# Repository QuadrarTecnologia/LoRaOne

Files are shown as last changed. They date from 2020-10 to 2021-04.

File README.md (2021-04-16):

# Quadrar Tecnologia ##

We are a Design House focused on IoT projects, working with large companies to solve complex challenges, developing innovative products.

## README #

## What is this repository for? ##
Quadrar's Public Repository for documents, application notes, example codes and usage for the LoRaONE Module.

## How this repository is arranged? ##

This repository is arranged by sub folders:

* LoRaONE Application Notes - Module's application notes documents;

* LoRaONE Code Examples - Application and code examples for module's usage;

* LoRaONE DevBoard - Board's Gerber Files and BOM for manufacture;

* LoRaONE Documents - Module's Datasheet, Manuals and References;

## Extern References ##

* LoRaONE: primeiro módulo LoRa nacional de baixo custo: https://www.embarcados.com.br/loraone-primeiro-modulo-lora-nacional-de-baixo-custo/

* Conheça a Quadrar LoRaONE DevBoard : https://www.embarcados.com.br/quadrar-loraone-devboard/

* Webinar gravado para o Embarcados: Aplicando a LoRaONE DevBoard nos seus projetos de IoT: https://www.embarcados.com.br/webinars/webinar-aplicando-a-loraone-devboard-nos-seus-projetos-de-iot/

## Who do I talk to? ##

* Quadrar Tecnologia 	- contato@quadrar.com.br

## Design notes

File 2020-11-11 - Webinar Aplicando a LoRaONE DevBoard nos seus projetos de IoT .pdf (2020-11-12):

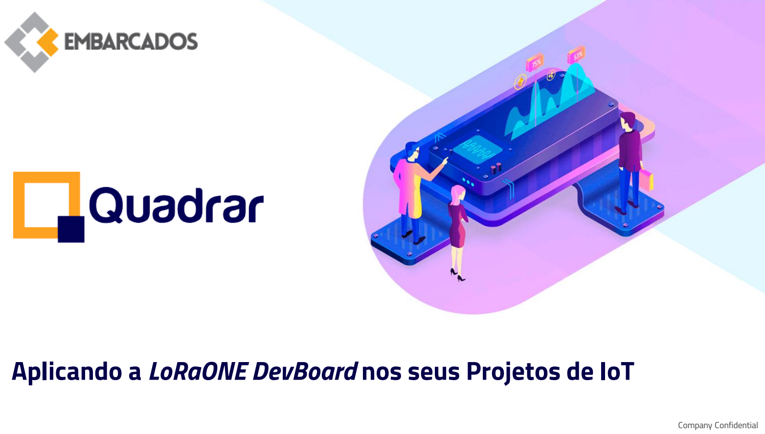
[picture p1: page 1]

# Aplicando a LoRaONE DevBoard nos seus Projetos de IoT

Company Confidential

A Quadrar Tecnologia (http://www.quadrar.com.br/) é uma Design House focada em projetos de IoT,

# trabalhando a mais de 10 anos com grandes empresas, para resolver

desafios complexos e desenvolvendo produtos inovadores.

# Nossos Clientes

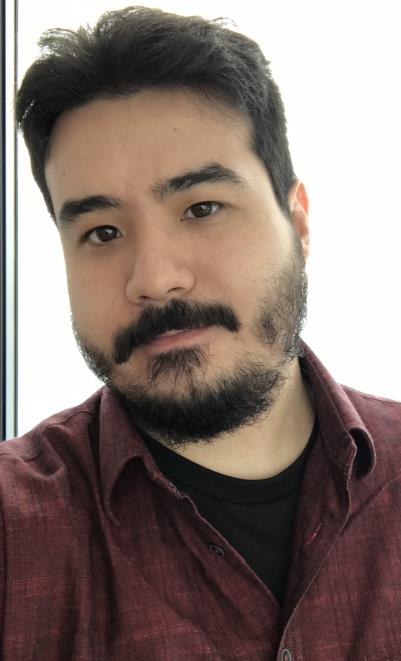
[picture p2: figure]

# Airton Toyofuku

## CTO e Engenheiro na Quadrar Tecnologia

### Engenheiro eletricista com vivência de mais de 10 anos na área de desenvolvimento de

sistemas embarcados, arquiteturas em nuvem e gestão de projetos.

### Possui formação em Engenharia Elétrica, com Ênfase em Eletrônica, Especialista em Controle e Automação, ambas pela FEI. Especialista em Projetos de Sistemas Digitais e

Eletrônica Embarcada pela SAE, e MBA em Gestão de Projetos pela FGV.
Por influência de grandes nomes do empreendedorismo, estuda técnicas de gestão, liderança, estratégia, economia, investimentos e inovação.
Nas horas vagas, é arqueiro, baixista, pescador e entusiasta do mercado financeiro.

# Apresentação

# 1. Apresentação 2. O que é LoRaWAN? 3. Características do Módulo LoRaONE 4. Características da DevBoard 5. Integração com Projetos IoT 6. Repositório de Conhecimento 7. Valores e Forma Aquisição 8. Referências 9. Agradecimentos

# Agenda

# O que é LoRaWAN?

# O que é LoRaWAN?

# O que é LoRaWAN?

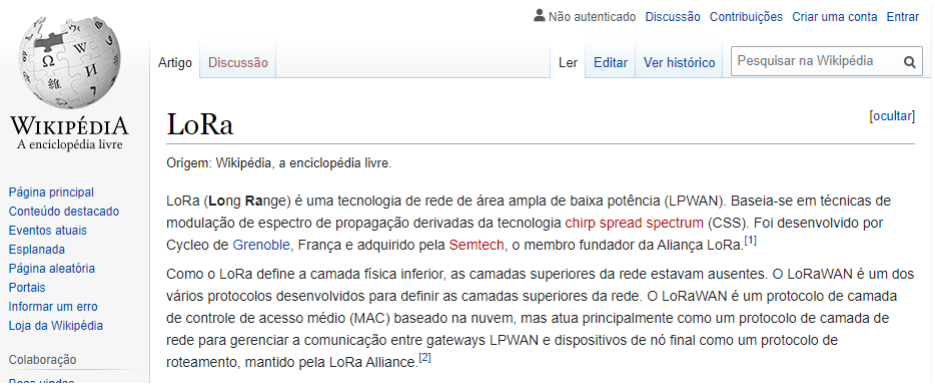
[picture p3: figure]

Fonte: https://pt.wikipedia.org/wiki/LoRa

# O que é LoRaWAN?

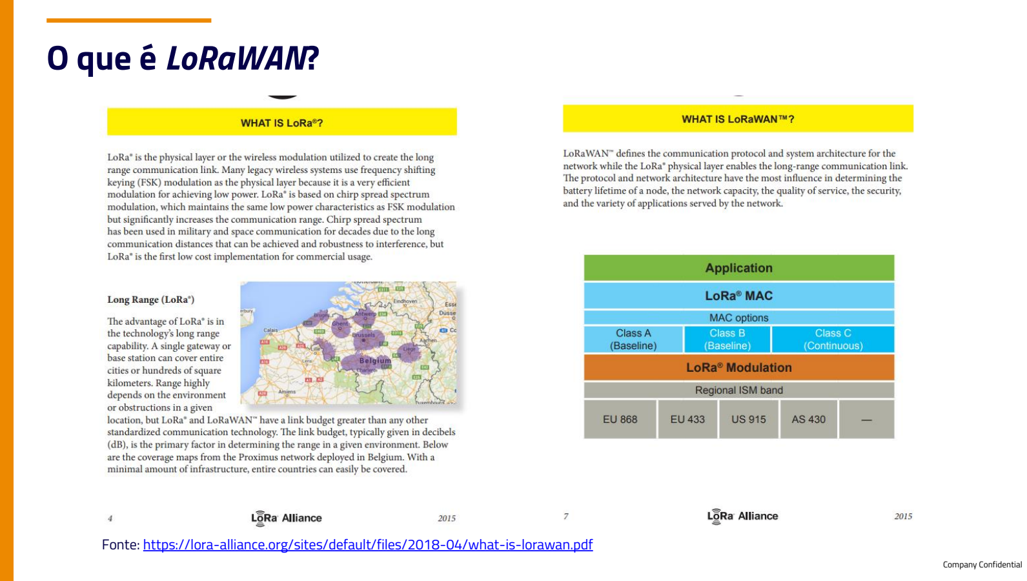
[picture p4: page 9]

Fonte: https://lora-alliance.org/sites/default/files/2018-04/what-is-lorawan.pdf

# O que é LoRaWAN?

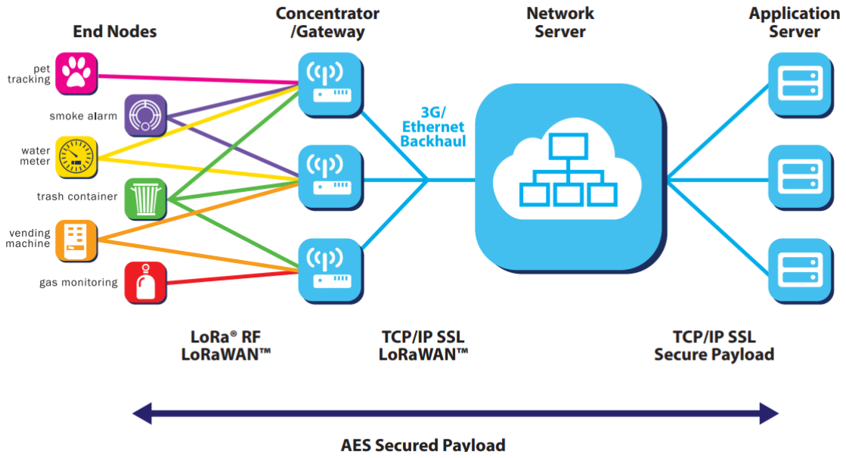
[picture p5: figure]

Fonte: https://lora-alliance.org/sites/default/files/2018-04/what-is-lorawan.pdf

# O que é LoRaWAN?

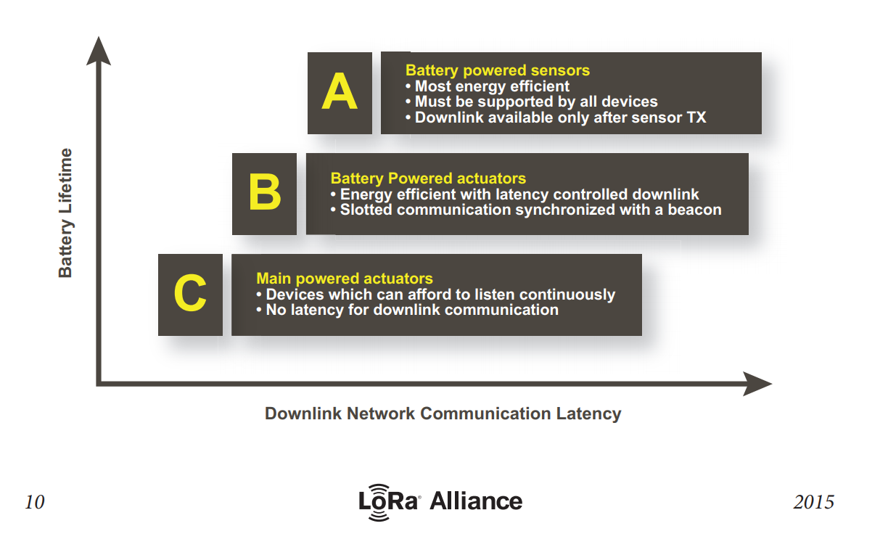
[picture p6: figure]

Fonte: https://lora-alliance.org/sites/default/files/2018-04/what-is-lorawan.pdf

# Características do Módulo LoRaONE

# Características do Módulo LoRaONE

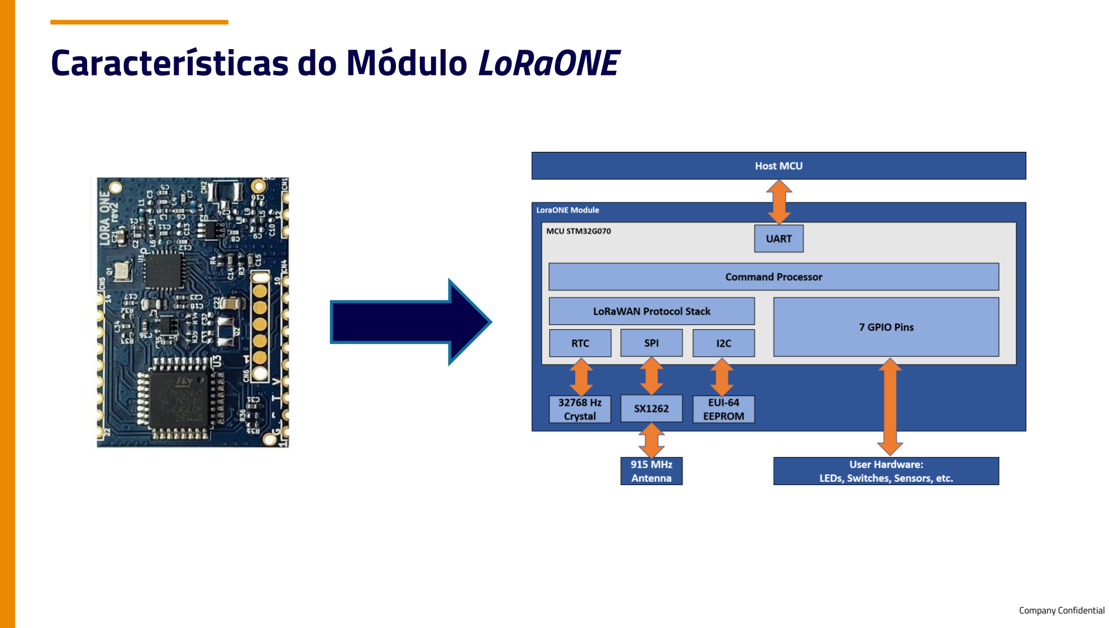
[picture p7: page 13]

# Características do Módulo LoRaONE

Specification | Min. | Typ. | Max | Units
Core MCU | STM32G070CB/KB
Core Radio | Semtech SX1262
Supply Voltage | 3.1 | 3.3 | 3.6 | V
Consumption in reception (LNA on) | | 5.3 | | mA
Consumption in reception (LNA off) | | 4.6 | | mA
Consumption in transmission at 22dBm | | 118 | | mA
Consumption in transmission at 20dBm | | 90 | | mA
Consumption in transmission at 17dBm | | 75 | | mA
Consumption in transmission at 14dBm | | 63 | | mA
Consumption in deep sleep mode | | 5 | | uA
Power-down reset threshold | 1.96 | 2.00 | 2.04 | V
GPIO pin current (each) | | 15 | | mA
GPIO pin current (total) | | 80 | | mA
Interface | UART
Baud rate | | 9600 | | bps
LoRaWAN band AU915/LA915 | 915 to 928 MHz
LoRaWAN network link budget - Reception | | 163 | | dBm
LoRaWAN network link budget - Transmission | | 159 | | dBm
Reception sensitivity | | -137 | | dBm
RF connection | three 50 Ohms options, see page 6
Operating temperature | -40 | | 85 | ºC
Operating humidity | 10 | | 90 | %

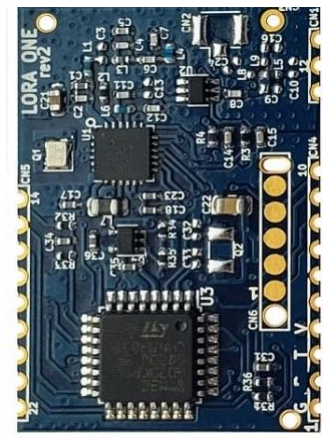
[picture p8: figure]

# Características do Módulo LoRaONE

Pin | Name | Description
1 | GND | Connected to Ground
2 | mRx | Connected to Host RX
3 | mTx | Connected to Host TX
4 | VCC | Connected to 3v3
5 | CTS | Serial flow control/GPIO
6 | RTS | Serial flow control/GPIO
7 | --- | Reserved
8 | RST | Reset
9 | --- | Reserved
10 | --- | Reserved
11 | GND | Connected to Ground
12 | Antenna | Antenna signal output
13 | GND | Connected to Ground
14 | VBAT | Battery Measurement
15 | GPIO7 | Generic GPIO
16 | GPIO6 | Generic GPIO
17 | GPIO5 | Generic GPIO
18 | GPIO4 | Generic GPIO
19 | GPIO3 | Generic GPIO
20 | GPIO2 | Generic GPIO
21 | GPIO1 | Generic GPIO
22 | GND | Connected to Ground

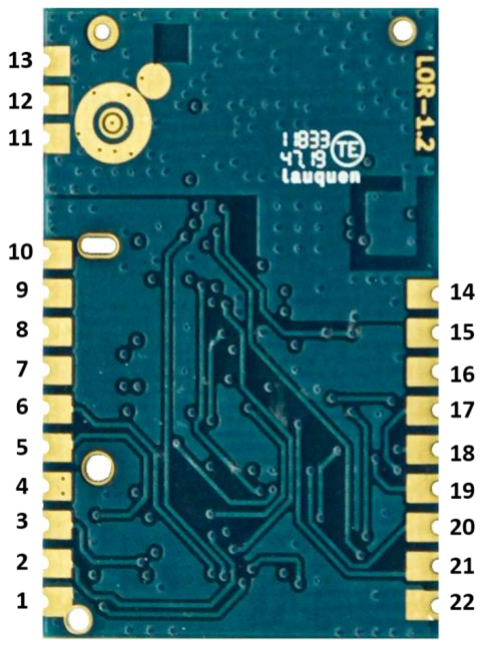
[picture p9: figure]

# Características do Módulo LoRaONE

# Características do Módulo LoRaONE

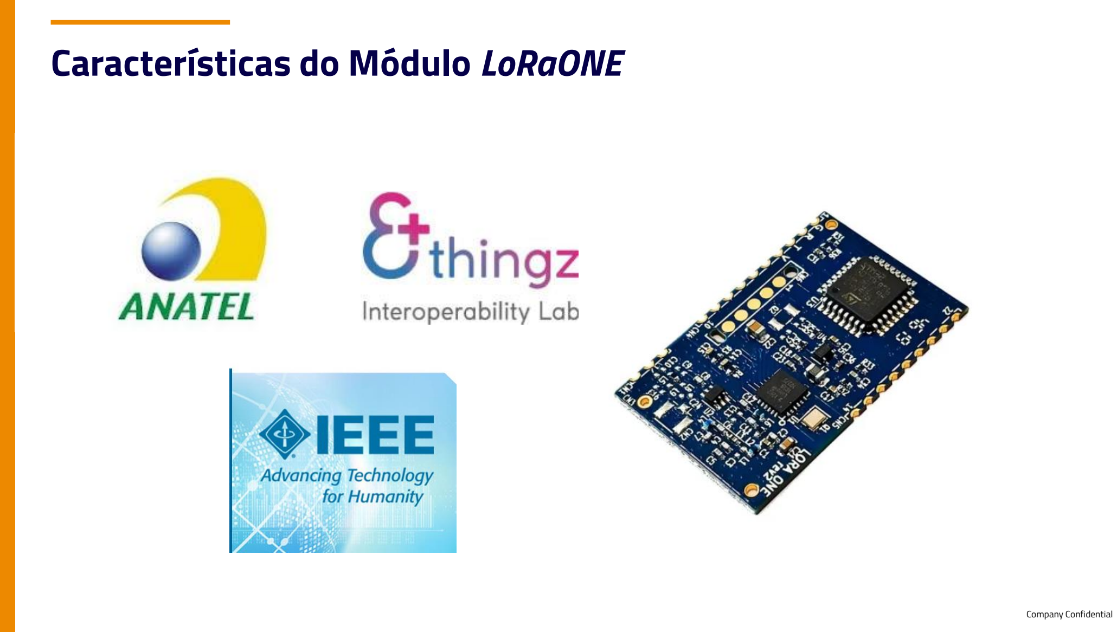
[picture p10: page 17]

# Características da DevBoard

# Características da DevBoard

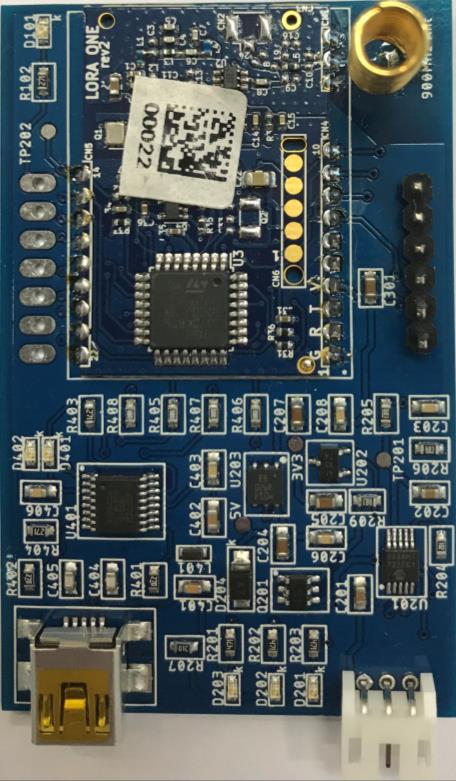
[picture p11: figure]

Além das características do Módulo LoRaONE...

✓ Alimentação via Mini USB com entrada de 5,0 Volts;
✓ Conversor USB-Serial FTDI, para acesso ao console de comandos AT;
✓ Circuito carregador de bateria, baseado no MCP73833, com LEDs de indicação de carga; ✓ Chave Eletrônica para comutação automática entre bateria e fonte principal;
✓ LDO de 3,3 Volts / 2,0 Amperes;
✓ Acesso aos GPIOs via Header Pin;
✓ Acesso a USART de comandos AT via Header Pin;
✓ Acesso a 3,3 Volts, 5,0 Volts e GND via Header Pin; ✓ Antena Helicoidal de 4dBI, customizável;
✓ Dimensões de 63,5 x 40 mm;

# Características da DevBoard

Pronta para sua aplicação que requer...

✓ Leitura de sensores diversos;
✓ Entradas e saídas digitais;
✓ Autonomia via bateria de lítio;
✓ Alimentação via fonte “simples” de 5,0 Volts;
✓ Possibilidade da customização do software do MCU;

# Integração com Projetos IoT

# Integração com Projetos IoT

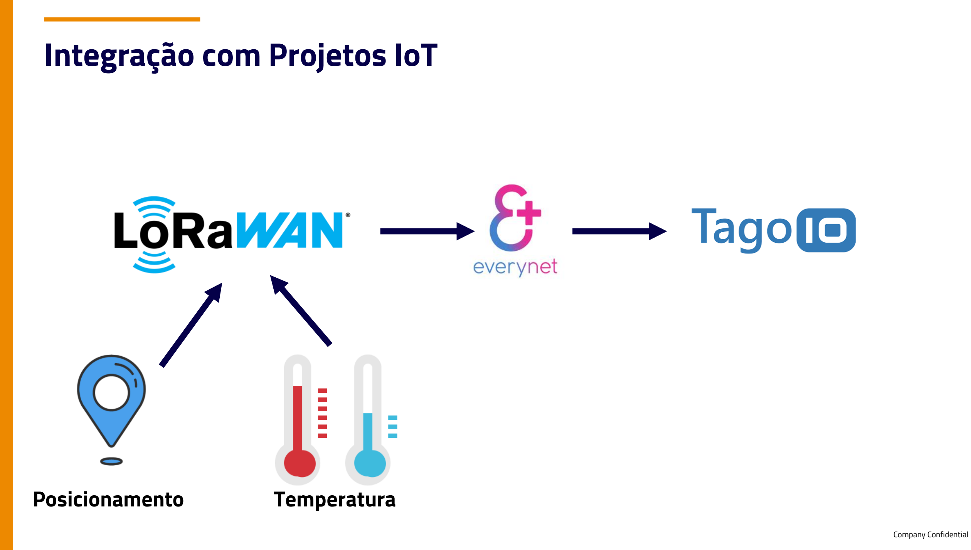
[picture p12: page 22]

# Posicionamento Temperatura

# Integração com Projetos IoT

# Integração com Projetos IoT

GPS TX | 5,0 Volts | LoRa TX
GPS RX | GND | LoRa RX
5,0 Volts | Data OneWire (Resistor de 10k – 3V3) | 5,0 Volts
GND | | GND

# Integração com Projetos IoT

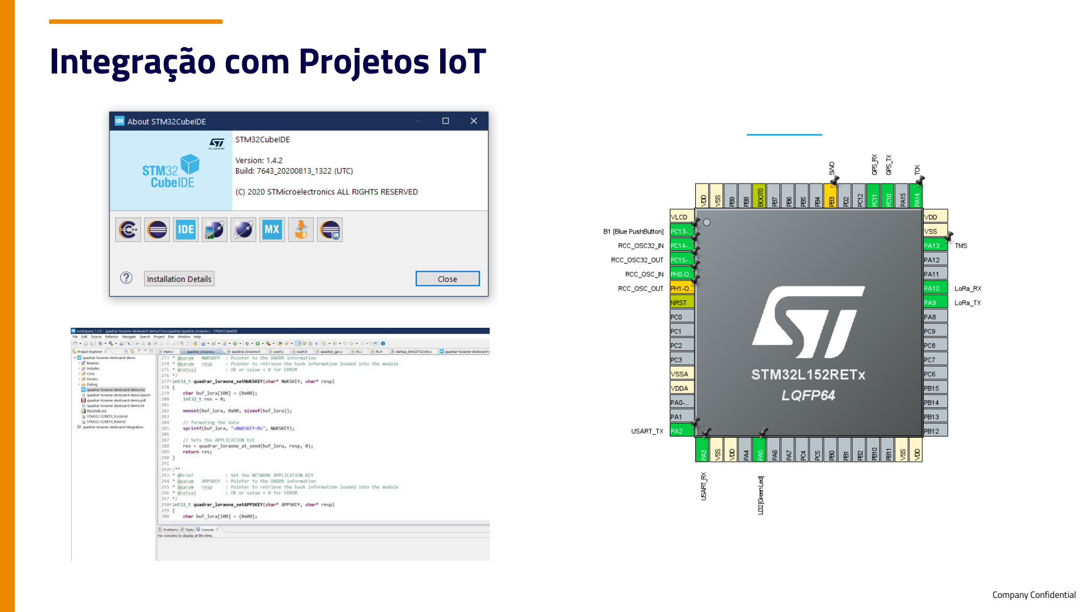
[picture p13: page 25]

# Integração com Projetos IoT

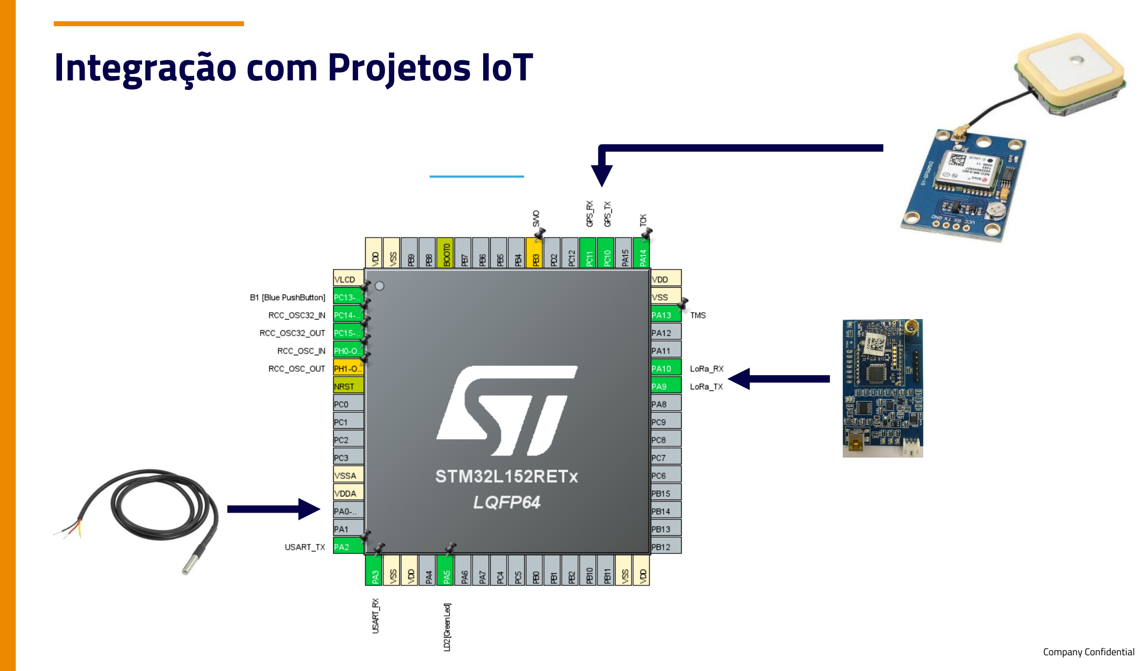
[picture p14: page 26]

# Integração com Projetos IoT

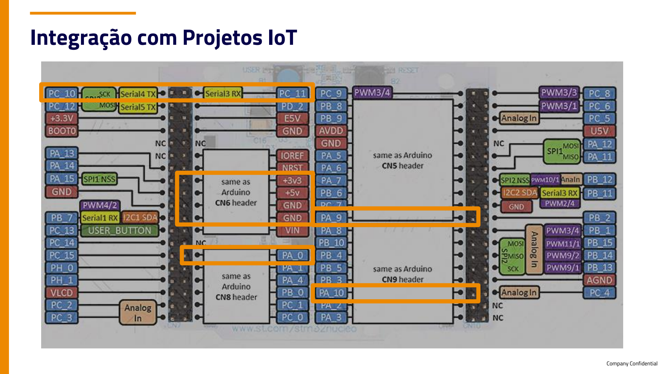
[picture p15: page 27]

# Integração com Projetos IoT

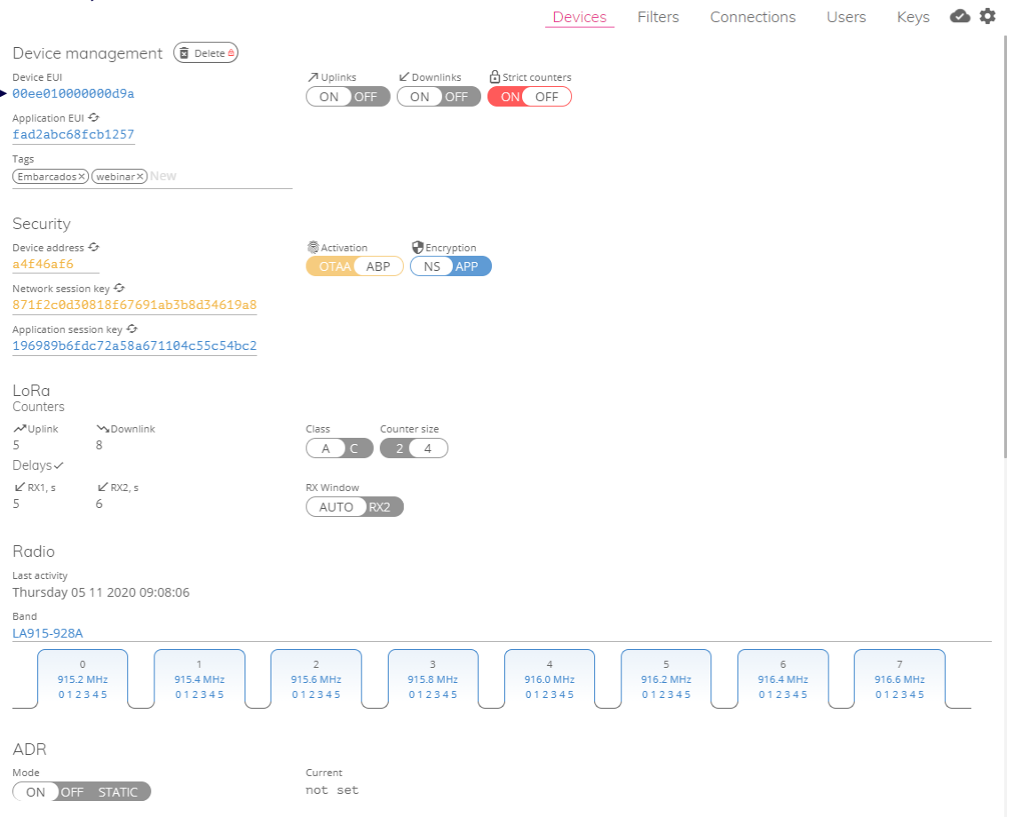
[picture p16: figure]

# Vem no Módulo

# Integração com Projetos IoT

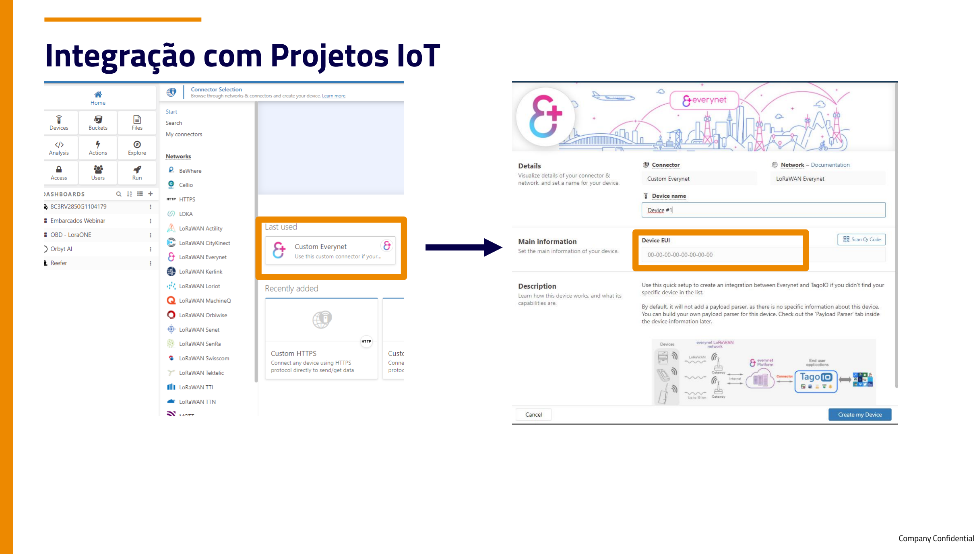
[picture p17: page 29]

# Integração com Projetos IoT

# Integração com Projetos IoT

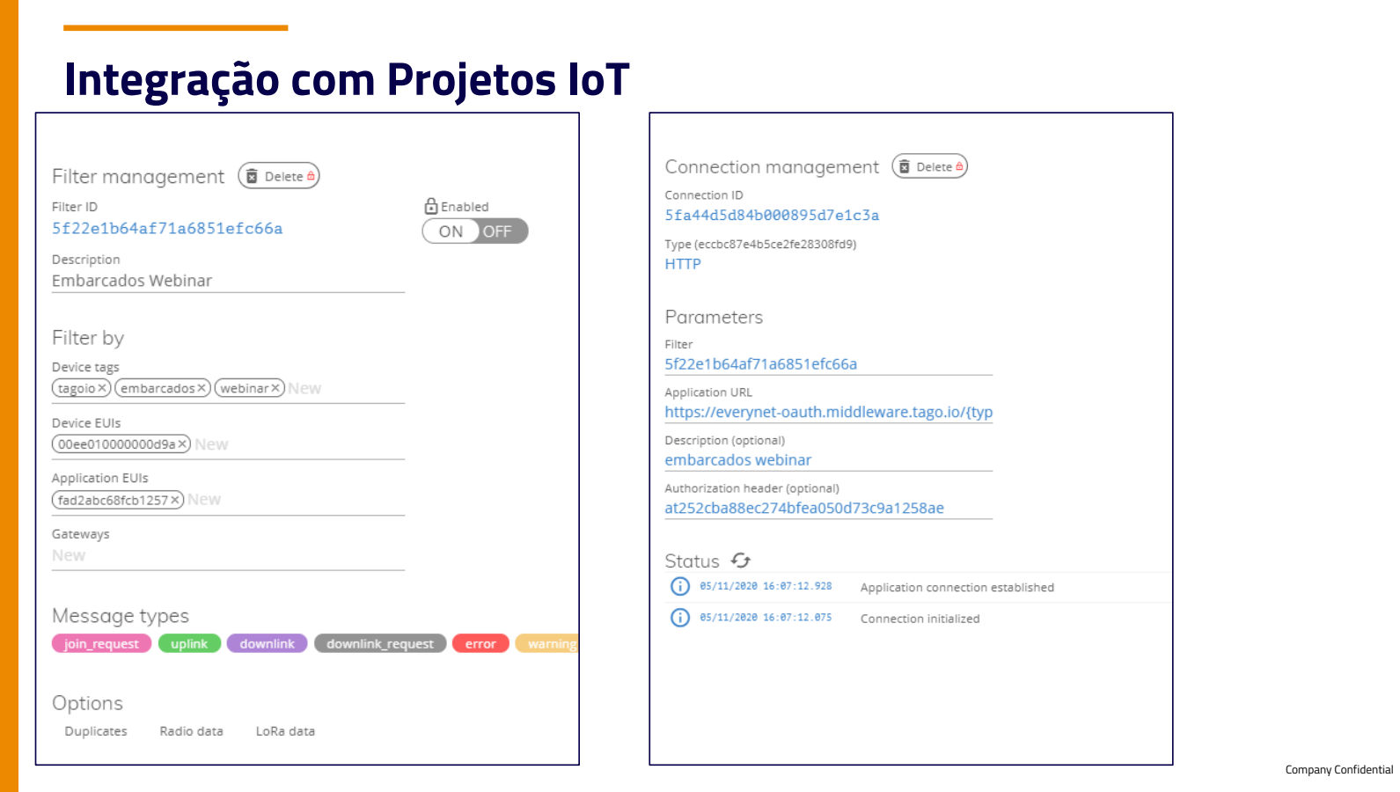
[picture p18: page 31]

# Integração com Projetos IoT

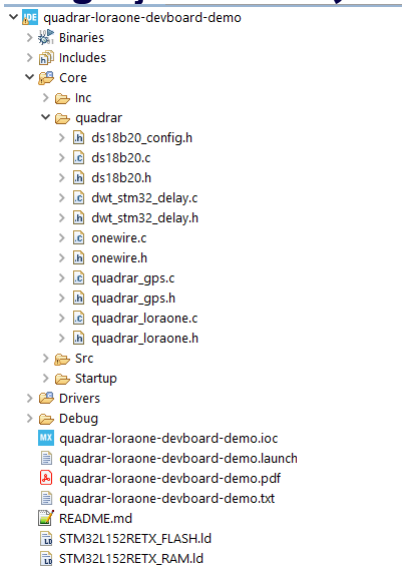
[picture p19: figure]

# Integração com Projetos IoT

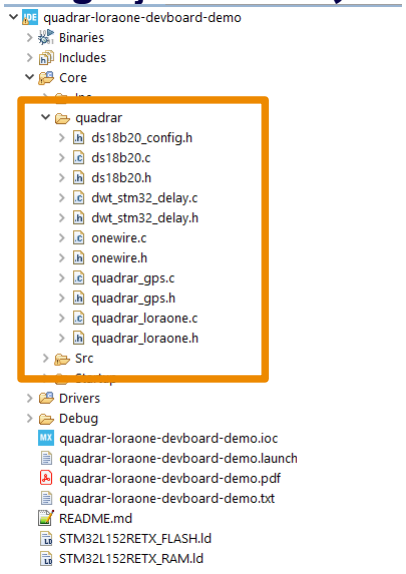
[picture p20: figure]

# Integração com Projetos IoT

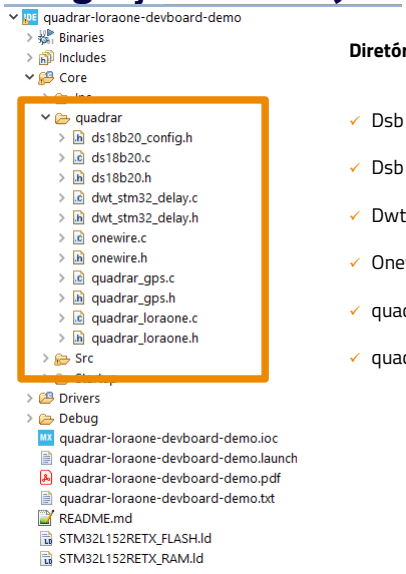
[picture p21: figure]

## Diretório quadrar:

✓ Dsb1820_config -> Configuração do GPIO para leitura do OneWire;
✓ Dsb1820.c/h -> Biblioteca do sensor de temperatura;
✓ Dwt_stm32_delay.c/h -> Controles de tempo para leitura do protocolo OneWire; ✓ Onewire.c/h -> Driver utilizado pelo sensor;
✓ quadrar_gps.c/h -> Biblioteca do GPS;
✓ quadrar_loraone.c/h -> Biblioteca de controle do módulo LoRaOne;

# Integração com Projetos IoT

// Everynet Information -> Must be exclusive for each device typedef struct
{
char* | DEUI;
char* | APPEUI;
char* | DADDR;
char* | NWKSKEY;
char* | APPSKEY;
} quadrar_loraone_data_t;

/* Publics function prototypes -----------------------------------------------*/
int32_t quadrar_loraone_init(void);
int32_t quadrar_loraone_reset(void);
int32_t quadrar_loraone_sleep(void);
int32_t quadrar_loraone_join(quadrar_loraone_join_t mode); int32_t quadrar_loraone_getDEUI (char* DEUI);
int32_t quadrar_loraone_setAPPEUI(char* APPEUI, char* resp); int32_t quadrar_loraone_setDADDR(char* DADDR, char* resp); int32_t quadrar_loraone_setNWKSKEY(char* NWKSKEY, char* resp); int32_t quadrar_loraone_setAPPSKEY(char* APPSKEY, char* resp); int32_t quadrar_loraone_send_data(int port, char* data);

# Integração com Projetos IoT

// Everynet Information -> Must be exclusive for each device
#define LoRaONE_APPEUI | (char*)"fad2abc68fcb1257"

#define LoRaONE_NWKSKEY | (char*)"871f2c0d30818f67691ab3b8d34619a8"

#define LoRaONE_APPSKEY | (char*)"196989b6fdc72a58a671104c55c54bc2"

#define LoRaONE_DADDR | (char*)"a4f46af6"

int main(void)
{
int32_t res = 0;
for(;;)
{
res = quadrar_loraone_init(); if(!res)
break;
}

for(;;)
{
quadrar_loraone_send_data(1,"BlaBlaBla!"); HAL_Delay(5000);
}

# Integração com Projetos IoT

Vamos a prática...

# Repositório de Conhecimento

# Repositório de Conhecimento

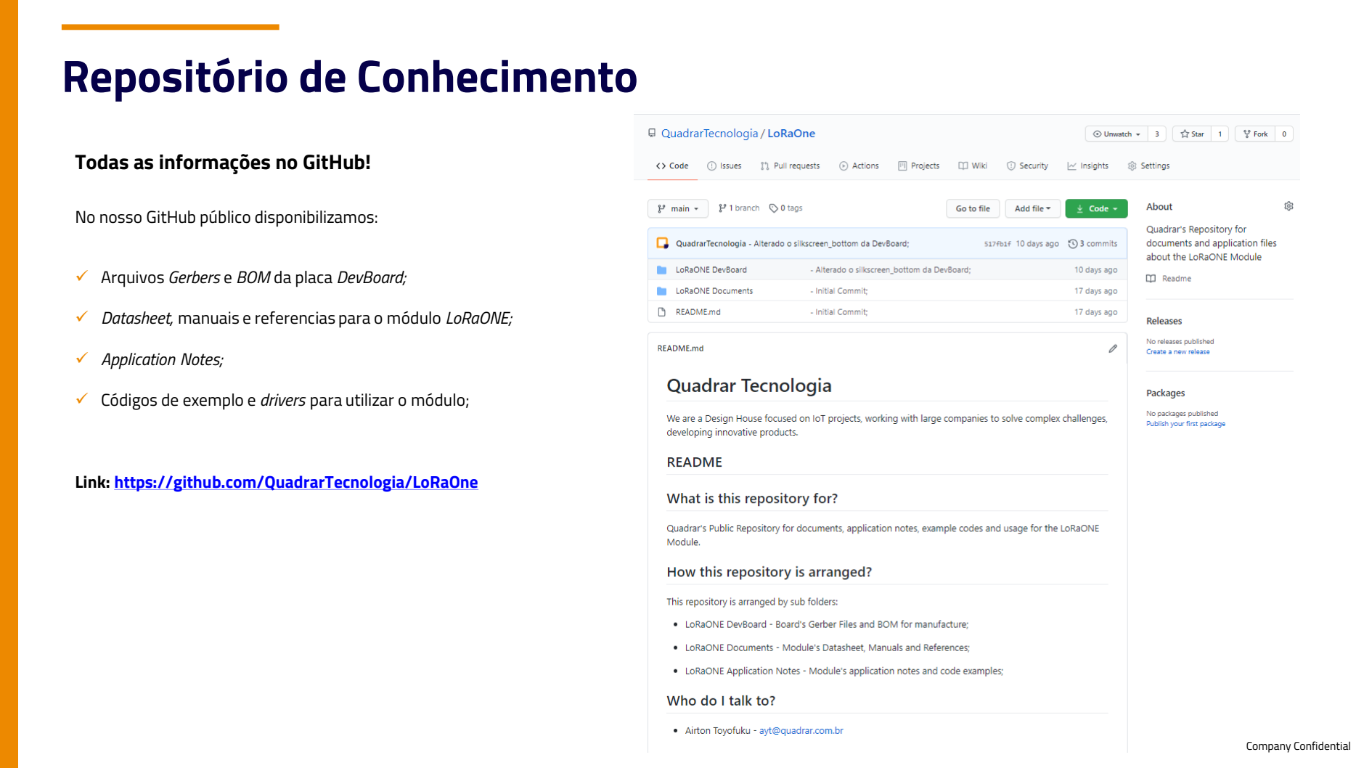
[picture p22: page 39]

### Todas as informações no GitHub!

No nosso GitHub público disponibilizamos:

✓ Arquivos Gerbers e BOM da placa DevBoard;
✓ Datasheet, manuais e referencias para o módulo LoRaONE; ✓ Application Notes;
✓ Códigos de exemplo e drivers para utilizar o módulo;

Link: https://github.com/QuadrarTecnologia/LoRaOne

# Valores e Formas de Aquisição

# Valores e Formas de Aquisição

### Os valores praticados para o Módulo LoRaONE são públicos:

Para volumes praticados na Industria, a tabela de valores é pública, já contabilizada com os impostos de PIS/COFINS, ICMS e IPI:

Para amostras, ou aquisição em baixos volumes, disponibilizamos um link no Mercado Livre para compra direta:
https://produto.mercadolivre.com.br/MLB-1432558473-modulo-lorawan-_JM?quantity=1.
Quantidade | Preço com Impostos (US$)
Até 10.000 | 16,90
10.001 a 50.000 | 16,12
50.001 a 100.000 | 15,35
mais de 100.000 | 14,57

# Valores e Formas de Aquisição

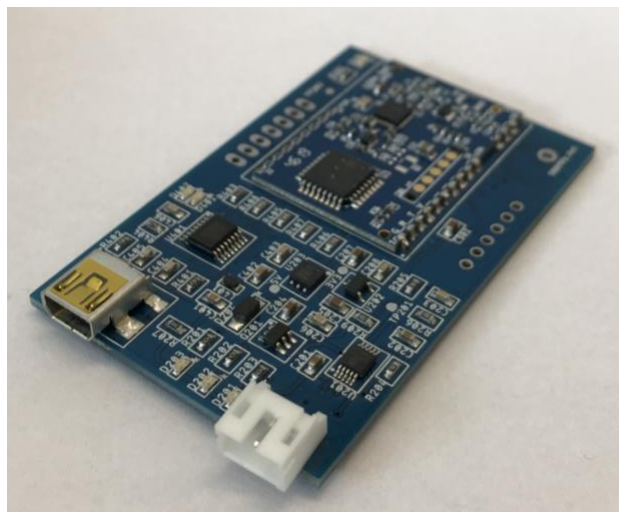
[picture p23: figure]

A expectativa de valor para a placa é de R$ 215,00, com previsão de disponibilidade em meados de dezembro de 2020.

O valor se deve ao baixo volume praticado para lotes iniciais de aquisição e ele pode ser negociado, dependendo da sua aplicação e volume, da mesma forma que é pratico pelo Módulo LoRaONE.

Também pode ser utilizada em projetos especiais, com customização de software, adequando-se a aplicação necessária.

Para amostras, ou aquisição em baixos volumes, disponibilizaremos um link no Mercado Livre para compra direta em Dezembro de 2020.

# Referências

# Referêcias

## LoRa segundo a Wekipedia: https://pt.wikipedia.org/wiki/LoRa

LoRaWAN pela LoRa Alliance: https://lora-alliance.org/sites/default/files/2018-04/what-is-lorawan.pdf

## Quadrar Tecnologia: https://quadrar.com.br

## Quadrar Tecnologia no Linkedin: https://www.linkedin.com/company/quadrartecnologia/

## Quadrar Tecnologia no Youtube: https://www.youtube.com/channel/UC3zlF7_kq0bqnCLDcLuwKrg

## Repositório da Quadrar Tecnologia no GitHub: https://github.com/QuadrarTecnologia/LoRaOne

LoRaONE no Mercado Livre: https://produto.mercadolivre.com.br/MLB-1432558473-modulo-lorawan-_JM?quantity=1.

## Application Server da Tago.io: https://tago.io/

## Network Server da Everynet: https://ns.atc.everynet.io/login

# Agradecimentos

Obrigado.

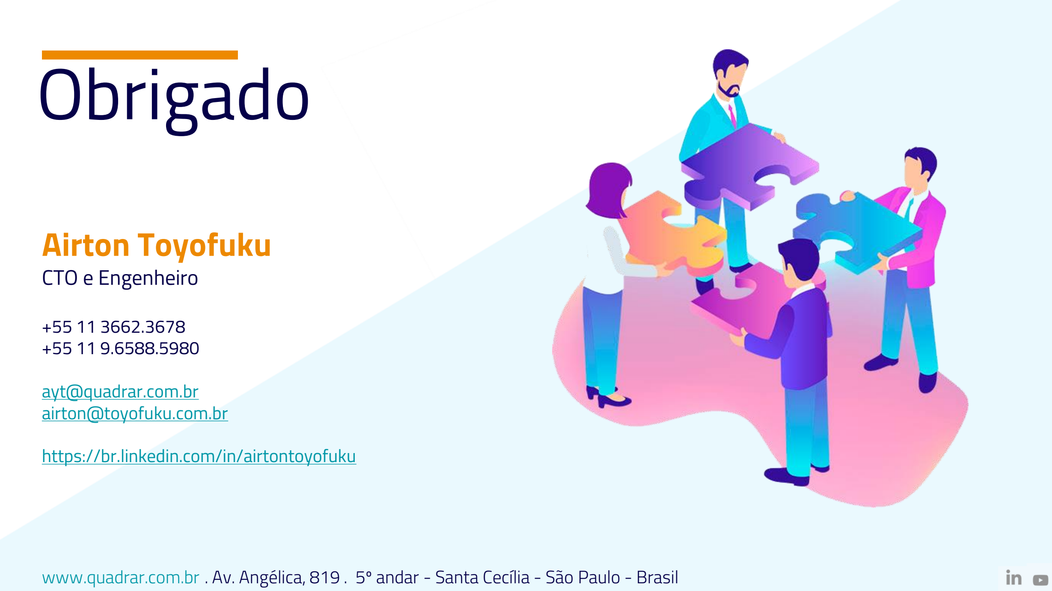
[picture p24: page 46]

## www.quadrar.com.br . Av. Angélica, 819 . 5º andar - Santa Cecília - São Paulo - Brasil

# Airton Toyofuku

## CTO e Engenheiro

+55 11 3662.3678
+55 11 9.6588.5980

## ayt@quadrar.com.br airton@toyofuku.com.br https://br.linkedin.com/in/airtontoyofuku

# Quadrar Tecnologia - Mais do que uma empresa de IoT Somos parceiros do seu negócio

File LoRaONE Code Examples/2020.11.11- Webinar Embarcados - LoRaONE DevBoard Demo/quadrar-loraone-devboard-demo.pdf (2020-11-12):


30/10/2020

quadrar-loraone-devboard-demo Project Configuration Report

## 1. Description

### 1.1. Project

Project Name | quadrar-loraone-devboard-demo
Board Name | NUCLEO-L152RE
Generated with: | STM32CubeMX 6.0.1
Date | 10/30/2020

### 1.2. MCU

MCU Series | STM32L1
MCU Line | STM32L151/152
MCU name | STM32L152RETx
MCU Package | LQFP64
MCU Pin number | 64

### 1.3. Core(s) information

Core(s) | Arm Cortex-M3

## 2. Pinout Configuration


## 3. Pins Configuration

Pin Number LQFP64 | Pin Name (function after reset) | Pin Type | Alternate Function(s) | Label
1 | VLCD | Power
2 | PC13-WKUP2 | I/O | GPIO_EXTI13 | B1 [Blue PushButton]
3 | PC14-OSC32_IN | I/O | RCC_OSC32_IN
4 | PC15-OSC32_OUT | I/O | RCC_OSC32_OUT
5 | PH0-OSC_IN | I/O | RCC_OSC_IN
6 | PH1-OSC_OUT * | I/O | RCC_OSC_OUT
7 | NRST | Reset
12 | VSSA | Power
13 | VDDA | Power
16 | PA2 | I/O | USART2_TX | USART_TX
17 | PA3 | I/O | USART2_RX | USART_RX
18 | VSS | Power
19 | VDD | Power
21 | PA5 ** | I/O | GPIO_Output | LD2 [Green Led]
31 | VSS | Power
32 | VDD | Power
42 | PA9 | I/O | USART1_TX | LoRa_TX
43 | PA10 | I/O | USART1_RX | LoRa_RX
46 | PA13 | I/O | SYS_JTMS-SWDIO | TMS
47 | VSS | Power
48 | VDD | Power
49 | PA14 | I/O | SYS_JTCK-SWCLK | TCK
51 | PC10 | I/O | UART4_TX | GPS_TX
52 | PC11 | I/O | UART4_RX | GPS_RX
55 | PB3 * | I/O | SYS_JTDO-TRACESWO | SWO
60 | BOOT0 | Boot
63 | VSS | Power
64 | VDD | Power

** The pin is affected with an I/O function
* The pin is affected with a peripheral function but no peripheral mode is activated

## 4. Clock Tree Configuration


## 5. Software Project

### 5.1. Project Settings

Name | Value
Project Name | quadrar-loraone-devboard-demo
Project Folder | D:\Workspace\STM32CubeIDE\workspace_1.2.0\quadrar-loraone-devboard-
Toolchain / IDE | STM32CubeIDE
Firmware Package Name and Version | STM32Cube FW_L1 V1.10.1
Application Structure | Advanced
Generate Under Root | Yes
Do not generate the main() | No
Minimum Heap Size | 0x200
Minimum Stack Size | 0x400

### 5.2. Code Generation Settings

Name | Value
STM32Cube MCU packages and embedded software | Copy only the necessary library files
Generate peripheral initialization as a pair of '.c/.h' files | Yes
Backup previously generated files when re-generating | No
Keep User Code when re-generating | Yes
Delete previously generated files when not re-generated | Yes
Set all free pins as analog (to optimize the power consumption) | Yes
Enable Full Assert | No

### 5.3. Advanced Settings - Generated Function Calls

Rank | Function Name | IP Instance Name
1 | MX_GPIO_Init | GPIO
2 | SystemClock_Config | RCC
3 | MX_USART2_UART_Init | USART2
4 | MX_RTC_Init | RTC
5 | MX_UART4_Init | UART4
6 | MX_USART1_UART_Init | USART1

## 6. Power Consumption Calculator report

### 6.1. Microcontroller Selection

Series | STM32L1
Line | STM32L151/152
MCU | STM32L152RETx
Datasheet | DS10002_Rev8

### 6.2. Parameter Selection

Temperature | 25
Vdd | 3.0

### 6.3. Battery Selection

Battery | Li-SOCL2(A3400)
Capacity | 3400.0 mAh
Self Discharge | 0.08 %/month
Nominal Voltage | 3.6 V
Max Cont Current | 100.0 mA
Max Pulse Current | 200.0 mA
Cells in series | 1
Cells in parallel | 1

### 6.4. Sequence

Step | Step1 | Step2
Mode | RUN | STOP
Vdd | 3.0 | 3.0
Voltage Source | Battery | Battery
Range | Range1-High | NoRange
Fetch Type | FLASH | n/a
CPU Frequency | 32 MHz | 0 Hz
Clock Configuration | HSI PLL | ALL CLOCKS OFF
Clock Source Frequency | 16 MHz | 0 Hz
Peripherals
Additional Cons. | 0 mA | 0 mA
Average Current | 8.7 mA | 560 nA
Duration | 0.1 ms | 0.9 ms
DMIPS | 33.0 | 0.0
Ta Max | 103.8 | 105
Category | In DS Table | In DS Table

### 6.5. Results

Sequence Time | 1 ms | Average Current | 870.5 µA
Battery Life | 5 months, 9 days, 22 hours | Average DMIPS | 33.0 DMIPS

### 6.6. Chart


## 7. IPs and Middleware Configuration

### 7.1. GPIO

### 7.2. RCC

High Speed Clock (HSE): BYPASS Clock Source Low Speed Clock (LSE) : Crystal/Ceramic Resonator
7.2.1. Parameter Settings:

System Parameters:

VDD voltage (V) | 3.3
Instruction Cache | Enabled
Prefetch Buffer | Disabled
Data Cache | Enabled
Flash Latency(WS) | 1 WS (2 CPU cycle)
RCC Parameters:
HSI Calibration Value | 16
MSI Calibration Value | 0
HSE Startup Timout Value (ms) | 100
LSE Startup Timout Value (ms) | 5000
Power Parameters:
Power Regulator Voltage Scale | Power Regulator Voltage Scale 1

### 7.3. RTC

mode: Activate Clock Source
WakeUp: Internal WakeUp
7.3.1. Parameter Settings:

General:

Hour Format | Hourformat 24
Asynchronous Predivider value | 127
Synchronous Predivider value | 255
Calendar Time:
Data Format | BCD data format
Hours | 0
Minutes | 0
Seconds | 0
Day Light Saving: value of hour adjustment | Daylightsaving None

Store Operation | Storeoperation Reset
Calendar Date:
Week Day | Monday
Month | January
Date | 1
Year | 0
Wake UP:
Wake Up Clock | 1 Hz with 1 bit added to Wake Up Counter *
Wake Up Counter | 0

### 7.4. SYS

Debug: Serial Wire
Timebase Source: SysTick

### 7.5. UART4

Mode: Asynchronous
7.5.1. Parameter Settings:

Basic Parameters:

Baud Rate | 9600 *
Word Length | 8 Bits (including Parity)
Parity | None
Stop Bits | 1
Advanced Parameters:
Data Direction | Receive and Transmit
Over Sampling | 16 Samples

### 7.6. USART1

Mode: Asynchronous
7.6.1. Parameter Settings:

Basic Parameters:

Baud Rate | 9600 *
Word Length | 8 Bits (including Parity)
Parity | None
Stop Bits | 1

Advanced Parameters:

Data Direction | Receive and Transmit
Over Sampling | 16 Samples

### 7.7. USART2

Mode: Asynchronous
7.7.1. Parameter Settings:

Basic Parameters:

Baud Rate | 115200
Word Length | 8 Bits (including Parity)
Parity | None
Stop Bits | 1
Advanced Parameters:
Data Direction | Receive and Transmit
Over Sampling | 16 Samples

* User modified value

## 8. System Configuration

### 8.1. GPIO configuration

IP | Pin | Signal | GPIO mode | GPIO pull/up pull down | Max Speed | User Label
RCC | PC14-OSC32_IN | RCC_OSC32_IN | n/a | n/a | n/a
| PC15-OSC32_OU T | RCC_OSC32_O UT | n/a | n/a | n/a
| PH0-OSC_IN | RCC_OSC_IN | n/a | n/a | n/a
SYS | PA13 | SYS_JTMS-SWDIO | n/a | n/a | n/a | TMS
| PA14 | SYS_JTCK-SWCLK | n/a | n/a | n/a | TCK
UART4 | PC10 | UART4_TX | Alternate Function Push Pull | Pull-up | High * | GPS_TX
| PC11 | UART4_RX | Alternate Function Push Pull | Pull-up | High * | GPS_RX
USART1 | PA9 | USART1_TX | Alternate Function Push Pull | No pull-up and no pull-down | High * | LoRa_TX
| PA10 | USART1_RX | Alternate Function Push Pull | No pull-up and no pull-down | High * | LoRa_RX
USART2 | PA2 | USART2_TX | Alternate Function Push Pull | No pull-up and no pull-down | High * | USART_TX
| PA3 | USART2_RX | Alternate Function Push Pull | No pull-up and no pull-down | High * | USART_RX
Single Mapped Signals | PH1-OSC_OUT | RCC_OSC_OUT | n/a | n/a | n/a
| PB3 | SYS_JTDO-TRACESWO | n/a | n/a | n/a | SWO
GPIO | PC13-WKUP2 | GPIO_EXTI13 | External Interrupt Mode with Rising edge trigger detection | No pull-up and no pull-down | n/a | B1 [Blue PushButton]
| PA5 | GPIO_Output | Output Push Pull | No pull-up and no pull-down | Very Low | LD2 [Green Led]

### 8.2. DMA configuration

nothing configured in DMA service

### 8.3. NVIC configuration

8.3.1. NVIC
Interrupt Table | Enable | Preenmption Priority | SubPriority
Non maskable interrupt | true | 0 | 0
Hard fault interrupt | true | 0 | 0
Memory management fault | true | 0 | 0
Pre-fetch fault, memory access fault | true | 0 | 0
Undefined instruction or illegal state | true | 0 | 0
System service call via SWI instruction | true | 0 | 0
Debug monitor | true | 0 | 0
Pendable request for system service | true | 0 | 0
System tick timer | true | 0 | 0
RTC wake-up interrupt through EXTI line 20 | true | 0 | 0
USART1 global interrupt | true | 0 | 0
UART4 global interrupt | true | 0 | 0
Flash global interrupt | unused
RCC global interrupt | unused
USART2 global interrupt | unused
EXTI line[15:10] interrupts | unused
8.3.2. NVIC Code generation
Enabled interrupt Table | Select for init sequence ordering | Generate IRQ handler | Call HAL handler
Non maskable interrupt | true | true | false
Hard fault interrupt | true | true | false
Memory management fault | true | true | false
Pre-fetch fault, memory access fault | true | true | false
Undefined instruction or illegal state | true | true | false
System service call via SWI instruction | true | true | false
Debug monitor | true | true | false
Pendable request for system service | true | true | false
System tick timer | true | true | true
RTC wake-up interrupt through EXTI line 20 | true | true | true
USART1 global interrupt | true | true | true
UART4 global interrupt | true | true | true

* User modified value

## 9. System Views

9.1. Category view
9.1.1. Current


## 10. Docs & Resources

Type | Link
Datasheet | http://www.st.com/resource/en/datasheet/DM00098321.pdf
Reference manual | http://www.st.com/resource/en/reference_manual/CD00240193.pdf
Programming manual | http://www.st.com/resource/en/programming_manual/CD00228163.pdf
Errata sheet | http://www.st.com/resource/en/errata_sheet/DM00104204.pdf
Application note | http://www.st.com/resource/en/application_note/CD00160362.pdf
Application note | http://www.st.com/resource/en/application_note/CD00167594.pdf
Application note | http://www.st.com/resource/en/application_note/CD00211314.pdf
Application note | http://www.st.com/resource/en/application_note/CD00259245.pdf
Application note | http://www.st.com/resource/en/application_note/CD00264342.pdf
Application note | http://www.st.com/resource/en/application_note/CD00264379.pdf
Application note | http://www.st.com/resource/en/application_note/CD00270081.pdf
Application note | http://www.st.com/resource/en/application_note/CD00273528.pdf
Application note | http://www.st.com/resource/en/application_note/CD00280599.pdf
Application note | http://www.st.com/resource/en/application_note/DM00024853.pdf
Application note | http://www.st.com/resource/en/application_note/DM00025071.pdf
Application note | http://www.st.com/resource/en/application_note/DM00032987.pdf
Application note | http://www.st.com/resource/en/application_note/DM00040808.pdf
Application note | http://www.st.com/resource/en/application_note/DM00042534.pdf
Application note | http://www.st.com/resource/en/application_note/DM00073742.pdf
Application note | http://www.st.com/resource/en/application_note/DM00085385.pdf
Application note | http://www.st.com/resource/en/application_note/DM00087593.pdf
Application note | http://www.st.com/resource/en/application_note/DM00129215.pdf
Application note | http://www.st.com/resource/en/application_note/DM00158601.pdf
Application note | http://www.st.com/resource/en/application_note/DM00160482.pdf
Application note | http://www.st.com/resource/en/application_note/DM00188260.pdf

Application note | http://www.st.com/resource/en/application_note/DM00141025.pdf
Application note | http://www.st.com/resource/en/application_note/DM00220769.pdf
Application note | http://www.st.com/resource/en/application_note/DM00206898.pdf
Application note | http://www.st.com/resource/en/application_note/DM00257177.pdf
Application note | http://www.st.com/resource/en/application_note/DM00272912.pdf
Application note | http://www.st.com/resource/en/application_note/DM00226326.pdf
Application note | http://www.st.com/resource/en/application_note/DM00236305.pdf
Application note | http://www.st.com/resource/en/application_note/DM00296349.pdf
Application note | http://www.st.com/resource/en/application_note/DM00327191.pdf
Application note | http://www.st.com/resource/en/application_note/DM00354244.pdf
Application note | http://www.st.com/resource/en/application_note/DM00315319.pdf
Application note | http://www.st.com/resource/en/application_note/DM00380469.pdf
Application note | http://www.st.com/resource/en/application_note/DM00395696.pdf
Application note | http://www.st.com/resource/en/application_note/DM00445657.pdf
Application note | http://www.st.com/resource/en/application_note/DM00493651.pdf
Application note | http://www.st.com/resource/en/application_note/DM00536349.pdf
Application note | http://www.st.com/resource/en/application_note/DM00660597.pdf

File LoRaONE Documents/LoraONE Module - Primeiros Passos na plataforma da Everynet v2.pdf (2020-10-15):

# Primeiros Passos com o Módulo LoRaONE na plataforma da Everynet

## Introdução

O módulo LoRaONE da Quadrar Tecnologia, (https://www.quadrar.com.br/loraone) desenvolvido em parceria com a Enablers, (http://www.enablers.com.br/) nasceu com o intuito de preencher a lacuna do mercado nacional por módulos de comunicação low power e de longo alcance, conhecido como dispositivos LoRa (Long Range), cuja qualidade, confiabilidade, suporte, time-to-market, custo e, principalmente, o fator de importação são empecilhos para a maioria das empresas de tecnologias e serviços.

O LoRaONE é um módulo transmissor caracterizado por usar a tecnologia LPWAN (Low-Power Wide Area Network) a qual estabelece comunicação com a rede LoRaWAN. (https://lora-alliance.org/resource-hub/what-lorawanr) Faz o uso do protocolo de mesmo nome e pode operar nos modos: classe A e C, além disso, trabalha nas frequências AU915 e LA915, sendo respectivamente, a frequência da Austrália em 915 MHz e América Latina 915 MHz.

Neste artigo, faremos um pequeno tutorial, mostrando os primeiros passos para a utilização desse módulo, como configura-lo na rede Everynet e os comandos necessários para se enviar uma mensagem para a rede.
Configuração do hardware;

Pensado para aplicações em projetos profissionais, esse módulo requer algumas conexões mínimas para operação, conforme apresentado na figura 1.


Figura 1 - Esquema de ligação básica do módulo LoRaONE

O pino 4 é a alimentação do módulo, que idealmente deve ser ligada em uma fonte de tensão estabilizada de 3,3 Volts, juntamente com os capacitores de desacoplamento. O módulo não possui um LDO integrado, por isso, é muito importante se atentar ao nível de tensão aplicado neste pino.

Os pinos 1, 11 e 13 são a malha de GND do módulo, e devem ser ligados obrigatoriamente a um ponto de GND.

O pino 12 é a interface com a antena de 900MHz. É importante dizer que esse módulo possui três pontos em que a antena pode ser conectada, conforme apresentado na figura 2, porém eles não são mutuamente conectados, sendo que cada interface é oferecida dentre de um modelo especifico de montagem do módulo.


Figura 2 - Opções de conexão para antena

Para o caso desse artigo, indicamos a montagem através do pino 12, e utilizamos uma antena helicoidal de 900MHz, conforme figura 3.


Figura 3 - Antena Helicoidal de 900MHz

O pino 8 é o controle de Reset do módulo. Esta ligação é opcional, e se utilizada, deve ser roteada diretamente para um GPIO do host, ou deixada em aberto. O acionamento do circuito de reset é efetuado colocando esse pino em GND.

Os pinos 2 e 3 são a interface de comunicação com o host, tratando-se uma porta serial com baud rate de 9600bps. Deve ser ligada diretamente aos pinos de RX e TX, atentando-se ao esquema de ligação mostrada na figura 1.

Para o host, pode se utilizar um Arduino, um NodeMCU, uma placa Núcleo da ST, uma Raspberry Pi, ou simplesmente o seu PC, através de um conversor USB-Serial como o da figura
4. Para esse último caso, lembrar de utilizar, caso esteja disponível, o terminal de alimentação de 3,3 Volts, pois em muitos modelos é fornecida uma saída de 5 Volts e outra de 3,3 Volts.


Figura 4 - Conversor USB-Serial
Configuração na Everynet;

O primeiro passo para conectar o dispositivo a plataforma Everynet é tomar nota do número de identificação do módulo, o Device EUI. Para isso basta enviar o comando AT+DEUI=? através da comunicação serial. O módulo deve responder conforme abaixo:

AT+DEUI=?
849DCED711B6C6EF

OK

Este número é a identificação única deste módulo registrado no IEEE e que pode ser utilizado na Everynet para ativação do equipamento. Agora precisamos logar na nossa conta Everynet e efetuar o registro do dispositivo, através da aba devices, como indicado na figura 5.


Figura 5 - Tela de configuração do device na Everynet

Na tela de device management, temos o campo Device EUI, que é onde colocamos o número fornecido pelo módulo, conforme a figura 5.

O campo "Application EUI" é um número que identifica a sua aplicação na Everynet, e se refere ao destino dos pacotes recebidos pela rede. Neste exemplo vamos colocar qualquer número porque apenas queremos ver os pacotes chegando no dashboard da plataforma.

O módulo permite trabalhar em dois modos de ativação ABP e OTAA (over the air activation). Neste exemplo estamos utilizando o modo de ativação ABP.

Também é necessário configurar a banda de trabalho, pois esse módulo está preparado para funcionar como LA915-928A. Esta banda tem as mesmas frequências da banda AU915 utilizada na Austrália com a diferença que as janelas de recepção de downlink tem um delay de 5 e 6 segundos respectivamente.

Uma vez realizadas, as configurações devem ficar parecidas com a tela apresentada na figura 6.


Figura 6 - Configuração do dispositivo

Agora, para terminar basta clicar no botão save, e teremos configurado o dispositivo. Como próximo passo, iremos configurar o módulo com as informações de Application EUI, Device address, network session key e application session key, fornecidos pela plataforma, conforme abaixo.

AT+DEUI=?
849DCED711B6C6EF

OK
AT+APPEUI=B6529EB867099E03 OK

AT+DADDR=69765A2B
OK

AT+NWKSKEY=4ACDFE0062B8F9EC1D37AF4CD35C2211 +HASH: 0916B3A3

OK

AT+APPSKEY=B14252E743E3DCC2682428D6E5BC66B1 +HASH: 0916B3A3
OK

AT+NJM=0
OK

Agora, estamos prontos para enviar mensagens para a plataforma.
Teste de comunicação;

Vamos enviar um pacote de 1 byte na porta 1, e verificarmos se ela chega no dashboard, utilizando o comando AT+SENDB=01:01, conforme abaixo.

AT+SENDB=01:01
OK

+EVT: 007

+EVT: 015

+EVT: 015

+EVT: 004

Após a resposta de OK, vemos 4 mensagens espontâneas que representam eventos em que o módulo nos informa um evento 007, significando que a transmissão foi bem sucedida.

Após a transmissão, o módulo abre duas janelas de recepção para downlink de resposta do servidor. Os dois eventos 015 indicam que nada foi recebido nestas janelas. O evento 004 indica que todo o processo foi concluído e que é seguro desligar o módulo. Na figura 7 podemos ver que a plataforma da Everynet recebeu o pacote que enviamos, indicado pela seta verde.


Figura 7 – Recebimento da mensagem pela Everynet sem confirmação

Neste teste enviamos o pacote sem confirmação de recebimento. Do ponto de vista do módulo ele não sabe se o pacote foi recebido e chegou no destino.
Podemos verificar isto pelo comando AT+ CFM=?

AT+CFM=?
0
OK

O retorno 0 indica que estamos enviando pacotes sem confirmação. Vamos ativar a confirmação através do comando AT+CFM=1, e repetir o envio dos pacotes.

AT+CFM=1
OK

AT+SENDB=01:01
OK

+EVT: 007

+EVT: 006

+EVT: 011

Agora vemos 3 mensagens espontâneas após o OK. O evento 007 indica que a transmissão foi bem sucedida, o evento 006 indica que houve a recepção de um pacote de confirmação, e o evento 011 indica que a mensagem que enviamos foi confirmada pela Everynet

Ao verificarmos a plataforma da Everynet, na figura x, vemos uma seta verde que indica o nosso pacote transmitido e uma seta lilás, que indica um pacote de confirmação enviado pela rede.


Figura 8 – Recebimento da mensagem pela Everynet com confirmação

## Considerações finais

Com esse pequeno passo a passo, apresentamos as primeiras medidas para se integrar e utilizar o Modulo LoRaONE, juntamente com a plataforma da Everynet, tornando sua utilização em projetos profissionais uma tarefa simples e ágil.

## Quadrar Tecnologia

A Quadrar Tecnologia (https://www.quadrar.com.br/) é uma Design House (empresa de projetos) voltada para a Internet das Coisas (IoT) com mais de 10 anos de experiencia, atuando no mercado de projetos eletrônicos em parceria com grandes companhias, oferecendo soluções de alta tecnologia para casos de alta complexidade e resolvendo problemas complexos.

Para entrar em contato conosco: contato@quadrar.com.br

## Histórico

Versão | Data | Autor | Descrição
1 | 2020-02-03 | Airton Toyofuku | Inicial
2 | 2020-06-24 | Airton Toyofuku | Alteração da figura 1

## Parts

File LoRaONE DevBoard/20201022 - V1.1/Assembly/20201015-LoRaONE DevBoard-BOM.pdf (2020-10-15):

QUADRAR TECNOLOGIA
Av. Angelica 819 - CJ 54
São Paulo / SP - 01227-000 +55 11 2628-5183
http://www.quadrar.com.br
Projeto | Cliente :
LoRaONE DevBoard | Produto : | LoRaONE DevBoard
| Modelo (Montagem) : | 01
| Emissão da BOM : | 03
ITEM | TIPO | QTD. | UNID. | DESCRIÇÃO | FABRICANTE | PARTNUMBER FABRICANTE | REFERÊNCIA
1 | | 1 | | Antena C-3POEM915S4 Monopolo Spiral OEM 915Mhz | C-3PO Tecnologia | C-3POEM915S4 | ANT301
2 | | 2 | | CAP CER 1UF 25V X5R 0603 | Yageo | CC0603KRX5R8BB105 | C201, C202
3 | | 5 | | CAP CER 1000PF 25V X7R 0603 | Yageo | AC0603KRX7R8BB102 | C203, C206, C208, C403, C406
4 | | 4 | | CAP CER 10UF 25V X5R 0603 | Yageo | CC0603MRX5R8BB106 | C301, C204, C205, C207
5 | | 1 | | CAP CER 10000PF 25V X7R 0603 | Yageo | CC0603KRX7R8BB103 | C401
6 | | 1 | | CAP CER 4.7UF 25V X5R 0603 | Yageo | CC0603KRX5R8BB475 | C402
7 | | 2 | | CAP CER 47PF 25V NPO 0603 | Yageo | CC0603JRNPO8BN470 | C404, C405
8 | | 6 | | LED BLUE 0603 SMD | Vishay Semiconductor Opto Division | VLMB1310-GS08 | D101, D201, D202, D203, D401, D402
9 | | 1 | | DIODE GEN PURP 1KV 1A MINISMA | Comchip Technology | CGRM4007-G | D204
10 | | 1 | | CONN HEADER VERT 3POS 2MM | JST Sales America Inc. | B3B-PH-K-S(LF)(SN) | J101
11 | | 1 | | CONN RCPT USB2.0 MINI AB SMD R/A | TE Connectivity AMP Connectors | 1775051-1 | J102
12 | | 1 | | NM | NM | NM | J103
13 | | 1 | | NM | NM | NM | J301
14 | | 1 | | NM | NM | NM | J104
15 | | 1 | | INDUCTORPOWER LINE 0603 47H 10% | KEMET | L0603B470KPWFT | L401
16 | | 1 | | P-CHANNEL,MOSFETS,SOT23-6L PACKA | Micro Commercial Co | SIL2301-TP | Q201
17 | | 3 | | RES SMD 270 OHM 5% 1/10W 0603 | Yageo | RC0603JR-07270RL | R102, R403, R404
18 | | 3 | | RES SMD 470 OHM 5% 1/10W 0603 | Yageo | RC0603JR-07470RL | R201, R202, R203
19 | | 1 | | RES SMD 1K OHM 5% 1/10W 0603 | Yageo | RC0603JR-071KL | R204
20 | | 3 | | RES SMD 68K OHM 1% 1/10W 0603 | Yageo | RC0603FR-0768KL | R205, R206, R209
21 | | 1 | | RES SMD 10K OHM 1% 1/10W 0603 | Yageo | RT0603FRE0710KL | R207
22 | | 2 | | RES SMD 27 OHM 1% 1/10W 0603 | Yageo | RC0603FR-0727RL | R401, R402
23 | | 4 | | RES SMD 0 OHM JUMPER 1/10W 0603 | Yageo | RC0603JR-070RL | R405, R406, R407, R408
24 | | 1 | | IC LI-ION/LI-POLY CTRLR 10MSOP | Microchip Technology | MCP73833T-AMI/UM | U201
25 | | 1 | | IC SUPERVISOR 1 CHANNEL 3SSOP | Rohm Semiconductor | BD48K35G-TL | U202
26 | | 1 | | IC REG LINEAR 3.3V 2A 6DFN | STMicroelectronics | LD39200PU33R | U203
27 | | 1 | | LoRaONE Module Quadrar - Enablers | Quadrar - Enablers | LoRaONE | U301
28 | | 1 | | IC USB SERIAL BASIC UART 16SSOP | FTDI, Future Technology Devices International Ltd | FT230XS-R | U401
Notas | Controle
| Elaborado por: Data: 15/10/2020 Airton Toyofuku Revisado por: Data:

# Lista de Materiais - BOM

Página 1 de 3

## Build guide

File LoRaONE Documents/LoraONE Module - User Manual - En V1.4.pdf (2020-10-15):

Long Range LoRaWAN Network Technology, Low-Power Transceiver Module

# LoRaONE

## Long Range LoRaWAN Network Technology Low-Power Transceiver Module

User Manual
V1.4

Long Range LoRaWAN Network Technology, Low-Power Transceiver Module

## Table of contents

Long Range LoRaWAN Network Technology, Low-Power Transceiver Module

## General Description

The LoRaONE transceiver module uses LPWan LoRa technology for communication with the LoRaWAN network.

The LoRaONE module acts as an AT command communication modem, using the LoRaWAN V1.0.3 protocol and can operate in the protocol classes A and C. It has been designed to be an easy to use, small size and low power AT command LoRaWAN module.

The LoRaONE module features RF, controller and API processor and it follows the AU915/LA915 profiles. The LoRaONE is Anatel and Everynet (EhThingz) certified, saving significant certification costs and time, and can be easily setup to the LoRaWAN network.

The LoRaONE module combines a small form factor 21.5 x 33 x 2.4 mm in castellation SMT format, with 7 GPIOs to connect and control sensors and actuators. The module is connected to a host MCU, through a 9600 bps UART, and can be easily used in a wide range IoT applications.

## Features

- Long range communication;
- Low power consumption;
- Supply voltage 3.1 – 3.6 Volts;
- Temperature range: -40°C to +85°C;
- Operates in 915 MHZ Band (AU915 and LA915 Profiles);
- Adjustable output power up to +20 dBm;
- High receiver sensitivity down to -137 dBm;
- Embedded LoRaWAN Class A and C Protocol;
- Easy to use AT command interface over a 9600 bps UART;
- 7 GPIO for control, status and ADC expansion;
- PCB mounting type: Castellation SMT;
- Anatel and Everynet EhThingz Certified;
- Environment friendly

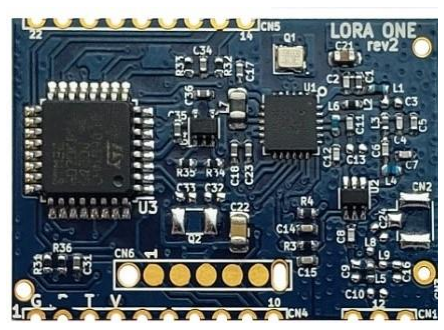
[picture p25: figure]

Figure 1 - LoRaONE Module

## Applications

- Internet of Things (IoT);
- Automation;
- Alarms, Access and Remote Control;
- Logistics, Retail and Tracking;
- Smart City
- Smart Home;
- Smart metering;
- Sensor Networks and Telemetry;
- Agriculture and livestock;

## Block Diagram

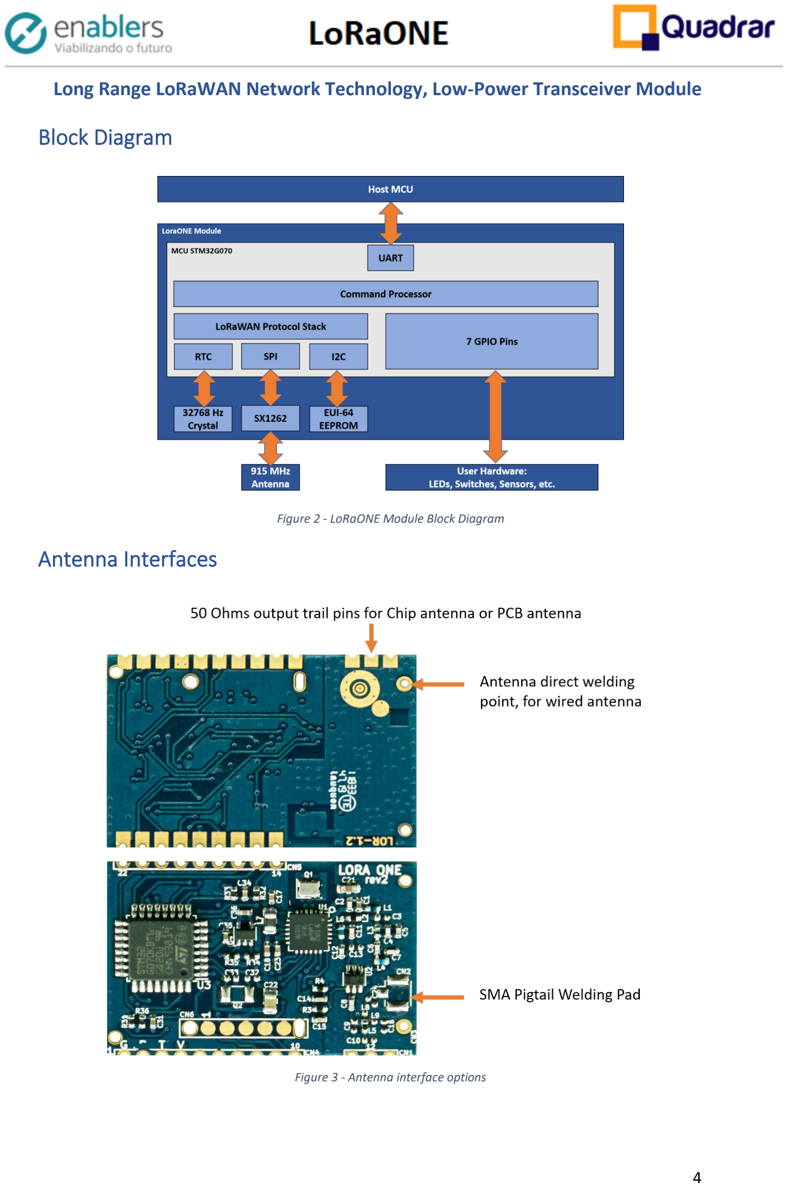
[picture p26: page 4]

Long Range LoRaWAN Network Technology, Low-Power Transceiver Module

Figure 2 - LoRaONE Module Block Diagram

## Antenna Interfaces

Figure 3 - Antenna interface options

Long Range LoRaWAN Network Technology, Low-Power Transceiver Module

## Pinout Description

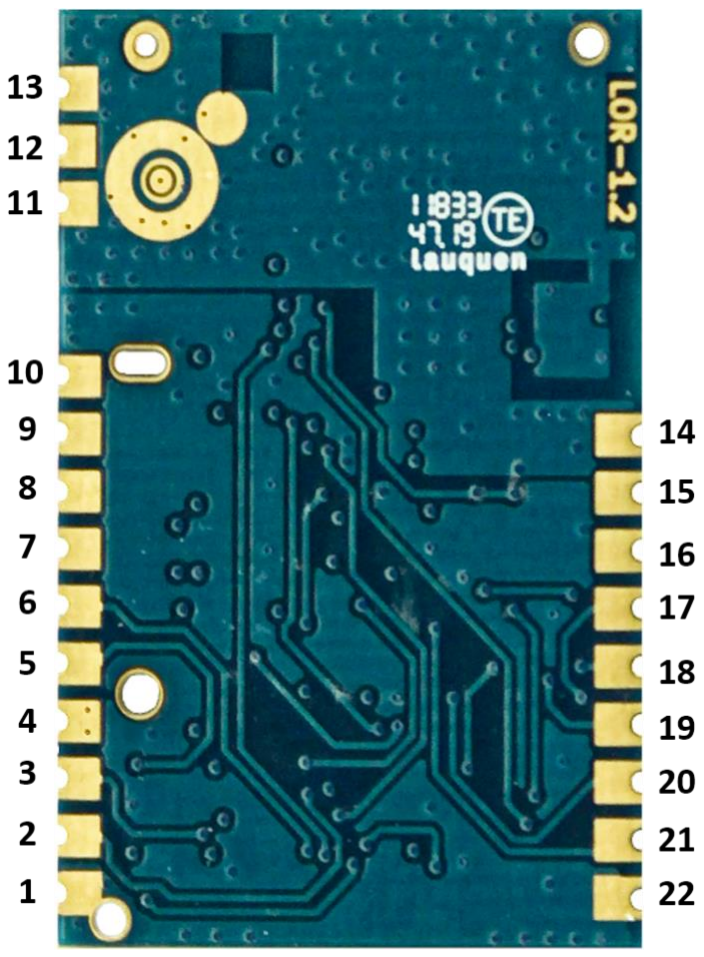
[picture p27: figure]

Figure 4 - LoRaONE Module pinout

Pin | Name | Description
1 | GND | Connected to Ground
2 | mRx | Connected to Host RX
3 | mTx | Connected to Host TX
4 | VCC | Connected to 3v3
5 | CTS | Serial flow control/GPIO
6 | RTS | Serial flow control/GPIO
7 | --- | Reserved
8 | RST | Reset
9 | --- | Reserved
10 | --- | Reserved
11 | GND | Connected to Ground
12 | Antenna | Antenna signal output
13 | GND | Connected to Ground
14 | VBAT | Battery Measurement
15 | GPIO7 | Generic GPIO
16 | GPIO6 | Generic GPIO
17 | GPIO5 | Generic GPIO
18 | GPIO4 | Generic GPIO
19 | GPIO3 | Generic GPIO
20 | GPIO2 | Generic GPIO
21 | GPIO1 | Generic GPIO
22 | GND | Connected to Ground
Table 1 - LoRaONE pinout descritption

Long Range LoRaWAN Network Technology, Low-Power Transceiver Module

## Module characteristics

The table 2 lists the LoRaONE module characteristics.

Specification | Min. | Typ. | Max | Units
Core MCU | STM32G070CB/KB*
Core Radio | Semtech SX1262**
Supply Voltage | 3.1 | 3.3 | 3.6 | V
Consumption in reception (LNA on) | | 5.3 | | mA
Consumption in reception (LNA off) | | 4.6 | | mA
Consumption in transmission at 22dBm | | 118 | | mA
Consumption in transmission at 20dBm | | 90 | | mA
Consumption in transmission at 17dBm | | 75 | | mA
Consumption in transmission at 14dBm | | 63 | | mA
Consumption in deep sleep mode | | 5 | | uA
Power-down reset threshold | 1.96 | 2.00 | 2.04 | V
GPIO pin current (each) | | 15 | | mA
GPIO pin current (total) | | 80 | | mA
Interface | UART
Baud rate | | 9600 | | bps
LoRaWAN band AU915/LA915 | 915 to 928 MHz
LoRaWAN network link budget - Reception | | 163 | | dBm
LoRaWAN network link budget - Transmission | | 159 | | dBm
Reception sensitivity | | -137 | | dBm
RF connection | three 50 Ohms options, see page 6
Operating temperature | -40 | | 85 | ºC
Operating humidity | 10 | | 90 | %

Table 2 - LoRaONE module characteristics

*See STM32G070 datasheet for more details. **See SX1262 datasheet for more details.

## AT Commands Interface

The AT commands have the standard format AT+[COMMAND][MODIFIER].

There are four command modifiers, as shown on table 3.

Modifier | Description | Example
? | Provides short help of the given command | AT+DEUI?
=[GIVEN] | Used to provide a parameter’s value to a command | AT+SEND=2:Hello
[NOTHING] | Used to run a command | AT+JOIN
=? | is used to get the value of a given command | AT+CFS=?
Table 3 - AT Commands modifiers

Long Range LoRaWAN Network Technology, Low-Power Transceiver Module

The response for the command is provided over the UART, following the standard format <value><CR><LF><Status<CR><LF>.

<CR> stands for “carriage return” and <LF> stands for “line feed”.

When no value is returned, the <value><CR><LF> format output is not returned.

Every command, except for ATZ that is used for the module Reset, returns a status response over the <Status><CR><LF> format. The possible status messages are shown on table 4.

Status Message | Description
OK | Command run correctly without error
AT_ERROR | Generic error
AT_PARAM_ERROR | A command parameter is incorrect
AT_BUSY_ERROR | The LoRa Network is busy, command not executed
AT_TEST_PARAM_OVERFLOW | A command parameter is too long
AT_NO_CLASSB_ENABLE | The end-node has not yet switched to Class B
AT_NO_NETWORK_JOINED | The end-node has not joined the LoRa network
AT_RX_ERROR | Error detected during command’s reception from the host MCU
Table 4 – Status Messages

Long Range LoRaWAN Network Technology, Low-Power Transceiver Module

The table 5 lists the AT Commands used by the module.

AT Command | Description
AT | Test command
ATZ | Reset
AT+DADDR | Receives/Establishes DevAddr
AT+APPKEY | Establishes AppKey
AT+APPSKEY | Establishes AppSKey
AT+NWKSKEY | Establishes NwkSKey
AT+APPEUI | Receives/Establishes AppEui/JoinEui
AT+ADR | Receives/Establishes The ADR
AT+TXP | Receives/Establishes Tx Power
AT+DR | Receives/Establishes the Data rate
AT+DCS | Receives/Establishes ETSI Duty Cycle
AT+PNM | Receives/Establishes the Public Network
AT+RX2FQ | Receives/Establishes rx2 frequency window
AT+RX2DR | Receives/Establishes the Rx2 window data rate
AT+RX1DL | Receives/Establishes the delay of the Rx1 window
AT+RX2DL | Receives/Establishes the DELAY of the RX2 window
AT+JN1DL | Receives/Establishes the delay of join window 1
AT+JN2DL | Receives/Establishes the delay of join window 2
AT+NJM | Receives/Establishes Join mode (0:ABP/1:OTAA)
AT+NWKID | Receives/Establishes Network ID
AT+CLASS | Receives/Establishes the class of the device (A/C)
AT+JOIN | Performs the join procedure
AT+NJS | Receives join status
AT+SENDB | Sends hexadecimal data along with the application port
AT+SEND | Sends text data along with the application port
AT+CFM | Receives/Establishes confirmation mode
AT+SNR | Receives the SNR from the last package received
AT+RSSI | Receives RSSI from the last package received
AT+BAT | Receives battery level
AT+TRSSI | Starts rf RSSI tone test
AT+TTONE | Starts rf tone test
AT+TTLRA | Starts the RF Tx LoRa test
AT+TRLRA | Starts rf Rx LoRa test
AT+CONF | Configures the LoRa RF test
AT+TOFF | Stops the RF test in progress
AT+CERTIF | Places the module in LoRaWAN Certification Mode
AT+EVTCFG | Enable or disable spontaneous events *
AT+RETRY | Get or set the number of retries in send command
AT+FACRES | Run factory reset
AT+FCU | Get or set the Uplink Frame Counter
AT+FCD | Get or set the Downlink Frame Counter
AT+DEUI | Get the Device EUI
AT+RECVB | print last received data in binary format (with hexadecimal
AT+RECV | print last received data in raw format
AT+CFS | Get confirmation status of the last AT+SEND (0-1)

Long Range LoRaWAN Network Technology, Low-Power Transceiver Module

AT Command | Description
AT+CAL | Start clock calibration
AT+CHIPID | Get the unique identification of the module
AT+VER | Get the firmware version
AT+LNA | Turns the LNA ON or OFF
AT+GPIOCFG | Configure a GPIO Pin (since firmware version 1.1.22)
AT+GPIO | Read or Write a GPIO Pin (since firmware version 1.1.22)
AT+SLEEP | Put the module in low power mode (since version 1.1.23)*
Table 5 – AT Commands

*In the AT+EVTCFG command, each bit means an event. For example, to activate the event 11 (1000 0000 000) use the command AT+EVTCFG=0x800 or AT+EVTCFG=2048.

*When the module is in sleep mode (after a AT+SLEEP), it can be waked from sleep by changing the state of GPIO1 pin.

The table 6 lists the events, as asynchronous notifications, used by the module.

Event | Description
+EVT: 003 | Notify Certification Test State
+EVT: 004 | An unconfirmed message ended (no more events are expected)
+EVT: 006 | We have received a packet (reception done)
+EVT: 007 | Transmission done
+EVT: 008, RSSI, snr | RSSI/snr of the last class C package received
+EVT: 009, RSSI, snr | RSSI/snr of the last class A or B package received
+EVT: 010, port | Port and given in hexadecimal received (downlink)
+EVT: 011 | Network Server ”ack” uplink data confirmed message transmission
+EVT 012 | Network Server is asking for an uplink transmission
+EVT 013, Class (A, B, C) | Switch to class X done
+EVT 014 | We have joined the network
+EVT 015 | The reception timed out
Table 6 – Events

Long Range LoRaWAN Network Technology, Low-Power Transceiver Module

The table 7 lists the AT Commands, with their respective parameters.

Commands | Input Parameters
AT+DADDR | 4 hexa separated by “:” or not
AT+APPKEY | 16 hexa separated by “:” or not
AT+APPSKEY | 16 hexa separated by “:” or not
AT+NWKSKEY | 16 hexa separated by “:” or not
AT+APPEUI | 8 hexa separated by “:” or not
AT+ADR | 0 or 1 (OFF or ON)
AT+TXP | 0 to 10
AT+DR | [0,1,2,3,4,5,6,7]
AT+DCS | 0 or 1 (OFF or ON)
AT+PNM | O or 1 (OFF or ON)
AT+RX2FQ | Frequency in Hz
AT+RX2DR | [0,1,2,3,4,5,6,7]
AT+RX1DL | <integer> representing mili seconds
AT+RX2DL | <integer> representing mili seconds
AT+JN1DL | <integer> representing mili seconds
AT+JN2DL | <integer> representing mili seconds
AT+NJM | 0 or 1 (OFF or ON)
AT+CLASS | A or C
AT+SENDB | <port>:<binary in hexa> Example 12:abcdef01
AT+SEND | Port:text (example 12:hello world)
AT+CFM | 0 or 1 (OFF or ON)
AT+RETRY | 0 to 8
AT+FCU | <integer>
AT+FCD | <integer>
AT+LNA | 0 or 1 (OFF or ON)
AT+GPIOCFG | <gpio pin [1~7]>,<Pin configuration [0~7]> Where pin configuration can be: 0 – unconfigured 1 - output initially left at 0 2 – output initially left at 1 3 – output open drain initially left open 4 – output open drain initially left close (grounded) 5 – input with no pull 6 – input with pull-up 7 – input with pull-down
AT+GPIO | <gpio pin [1~7]>,<Pin state> Where pin state can be: 0 – Write 0 to an output 1 – Write 1 to an output 2 – Read a pin

Table 7 - AT Commands parameters

Long Range LoRaWAN Network Technology, Low-Power Transceiver Module

## Typical Initialization Sequence

1. Set the global application identifier:

AT+APPEUI=33:33:33:33:33:33:33:33

OK

2. Set device address:

AT+DADDR=44:44:44:44

OK

3. Set Network Session Key:

AT+NWKSKEY=12:34:56:78:90:AB:CD:EF:12:34:56:78:90:AB:CD:EF

+HASH: 8A20C220

OK

4. Set Application session key:

AT+APPSKEY=12:34:56:78:90:AB:CD:EF:12:34:56:78:90:AB:CD:EF

+HASH: 8A20C220

OK

5. Set confirmation mode on:

AT+CFM=1

OK

6. Set to ABP initialization Mode:

AT+NJM=0

OK

7. Send 1 byte with content equal 0x01 (hexadecimal) in port 1

AT+SENDB=01:01

OK

Long Range LoRaWAN Network Technology, Low-Power Transceiver Module

## Typical Application Circuit

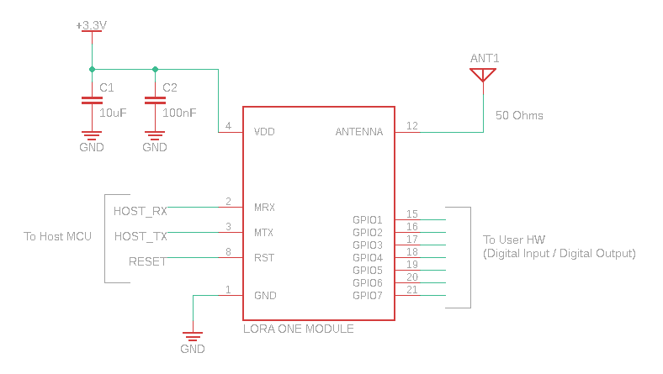
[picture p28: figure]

Figure 5- Application circuit

## Mechanical Specifications

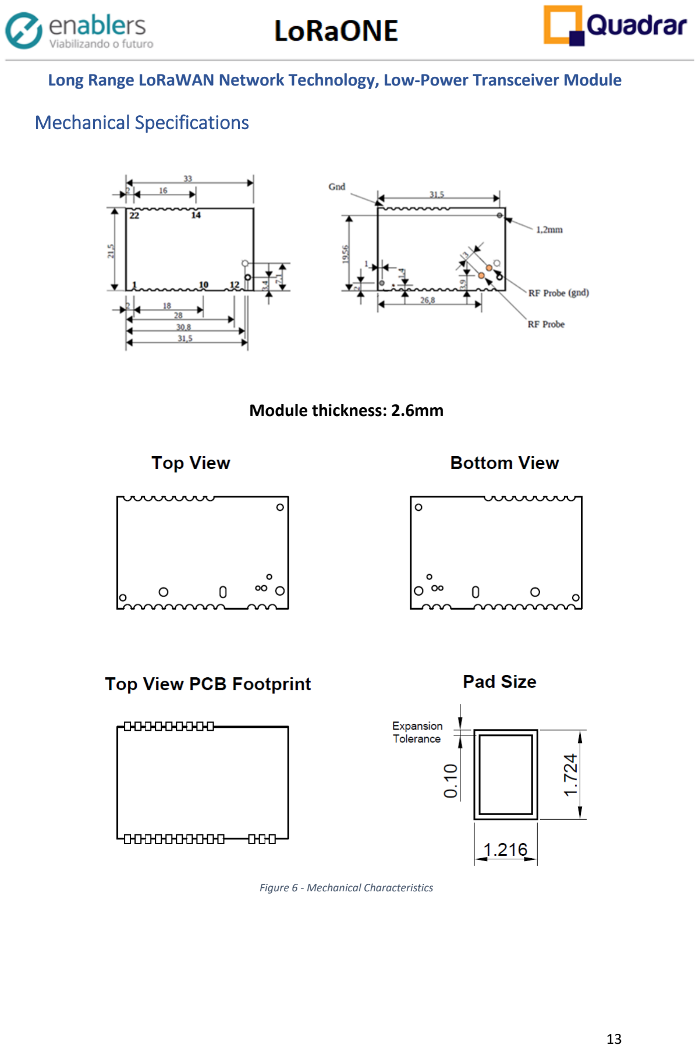
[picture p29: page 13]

Long Range LoRaWAN Network Technology, Low-Power Transceiver Module

Module thickness: 2.6mm

Figure 6 - Mechanical Characteristics

Long Range LoRaWAN Network Technology, Low-Power Transceiver Module

## Revision History

Version | Date | Author | Description
1.0 | 2020-02-03 | Marco Vettori | Initial
1.1 | 2020-02-10 | Paulo Pereira | 1. Updated table 5 with GPIO Commands. 2. Updated table 7 with GPIO Commands.
1.2 | 2020-03-11 | Paulo Pereira | 1. Updated table 5 with Sleep Command.
1.3 | 2020-06-09 | Airton Toyofuku | 1. Updated Revision History. 2. Updated text distribuition. 3. Correction of the terminals 2 and 3 for communication with de host mcu in table 1. 4. Correction of the terminal 1 from VDC to VCC 5. Updated the figure 5. 6. PCB thickness from 2.6 to 1.6mm
1.4 | 2020-08-03 | Airton Toyofuku | 1. Inclusion of current consumption information in deep sleep mode, in table 2.

Long Range LoRaWAN Network Technology, Low-Power Transceiver Module

## Contact

Quadrar Tecnologia em Serviços de Informática Ltda.

Avenida Angélica, 819, Ap. 54.

Santa Cecilia, São Paulo – SP – Brazil

ZIP 01227-000

Site: https://www.quadrar.com.br/

Support e-mail: contato@quadrar.com.br

PCB footprint download:

https://drive.google.com/file/d/1TNZ7rSfwNmq-HMUtwNazXkd5eTFpW8kj/view?usp=sharing

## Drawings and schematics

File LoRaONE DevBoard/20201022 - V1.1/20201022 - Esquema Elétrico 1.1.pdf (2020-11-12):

# 7 J103

A

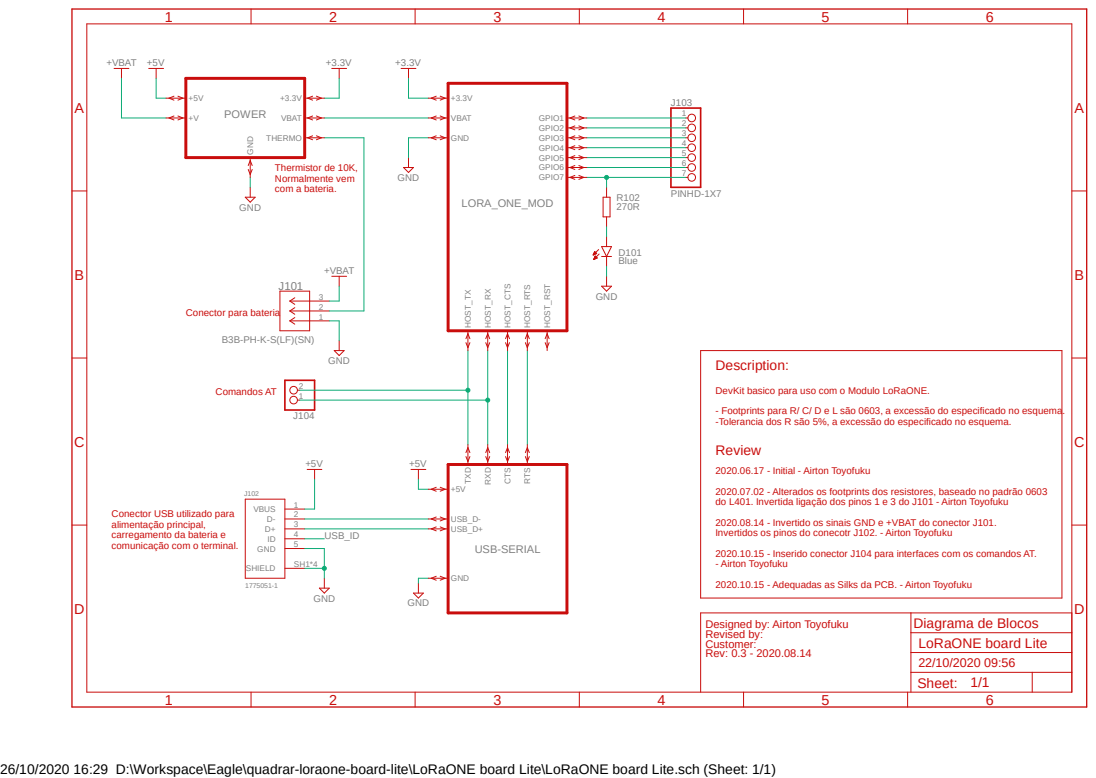
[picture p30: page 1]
GND; +VBAT; +VBAT +5V; Blue; PINHD-1X7; VBUS; SHIELD; POWER; VBAT; THERMO; LORA_ONE_MOD; GND HOST_TX; HOST_RX; HOST_CTS; HOST_RTS; HOST_RST; GPIO1 GPIO2 GPIO3 GPIO4 GPIO5 GPIO6 GPIO7; USB-SERIAL; USB_D- USB_D+; +5V TXD; RXD; CTS; RTS; USB_ID; Description:; Thermistor de 10K, Normalmente vem com a bateria.; Comandos AT

Conector para bateria

DevKit basico para uso com o Modulo LoRaONE.
- Footprints para R/ C/ D e L são 0603, a excessão do especificado no esquema.
-Tolerancia dos R são 5%, a excessão do especificado no esquema.
Review

2020.06.17 - Initial - Airton Toyofuku
2020.07.02 - Alterados os footprints dos resistores, baseado no padrão 0603
do L401. Invertida ligação dos pinos 1 e 3 do J101 - Airton Toyofuku
2020.08.14 - Invertido os sinais GND e +VBAT do conector J101.
Invertidos os pinos do conecotr J102. - Airton Toyofuku
2020.10.15 - Inserido conector J104 para interfaces com os comandos AT.
- Airton Toyofuku
2020.10.15 - Adequadas as Silks da PCB. - Airton Toyofuku

Conector USB utilizado para
alimentação principal,
carregamento da bateria e
comunicação com o terminal.

Designed by: Airton Toyofuku
Revised by:
Customer:
Rev: 0.3 - 2020.08.14

Diagrama de Blocos
LoRaONE board Lite
Sheet:

26/10/2020 16:29 D:\Workspace\Eagle\quadrar-loraone-board-lite\LoRaONE board Lite\LoRaONE board Lite.sch (Sheet: 1/1)

A

A

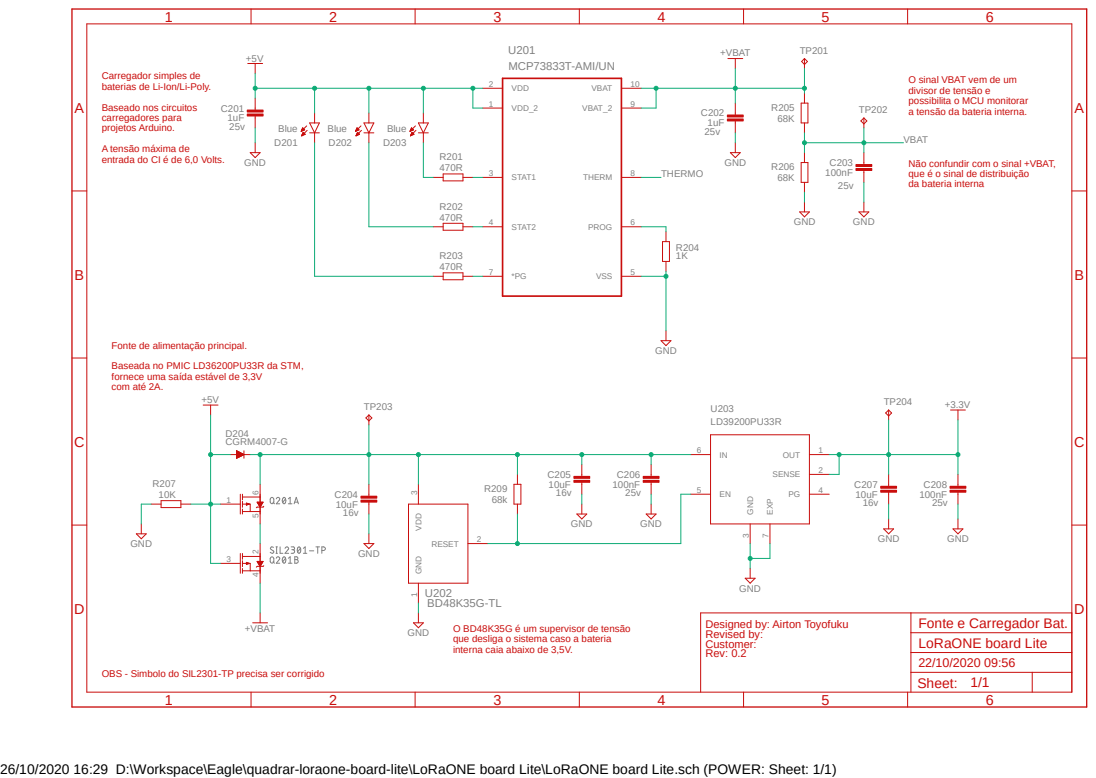
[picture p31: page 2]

Carregador simples de
baterias de Li-Ion/Li-Poly.
Baseado nos circuitos
carregadores para
projetos Arduino.
A tensão máxima de
entrada do CI é de 6,0 Volts.

O sinal VBAT vem de um
divisor de tensão e
possibilita o MCU monitorar
a tensão da bateria interna.

Não confundir com o sinal +VBAT,
que é o sinal de distribuição
da bateria interna

Fonte de alimentação principal.
Baseada no PMIC LD36200PU33R da STM,
fornece uma saída estável de 3,3V
com até 2A.

O BD48K35G é um supervisor de tensão
que desliga o sistema caso a bateria
interna caia abaixo de 3,5V.

Designed by: Airton Toyofuku
Revised by:
Customer:
Rev: 0.2

OBS - Simbolo do SIL2301-TP precisa ser corrigido

26/10/2020 16:29 D:\Workspace\Eagle\quadrar-loraone-board-lite\LoRaONE board Lite\LoRaONE board Lite.sch (POWER: Sheet: 1/1)

A

A

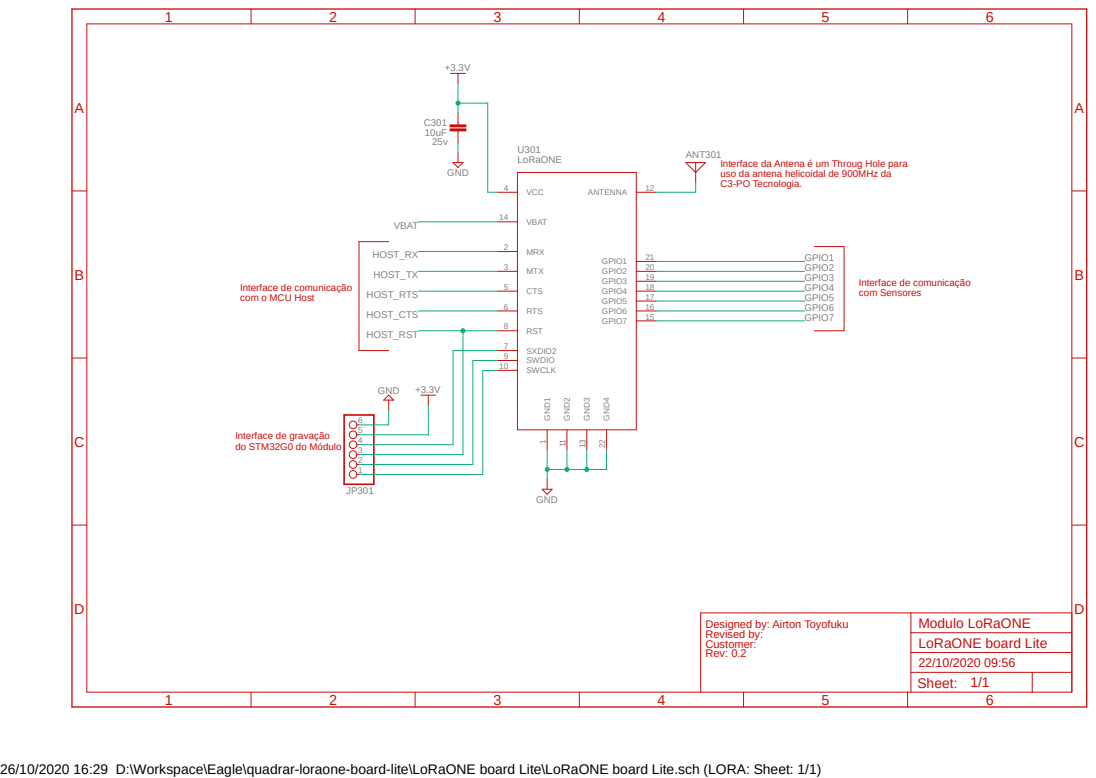
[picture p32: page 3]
LoRaONE; GND; VCC 4; MRX 2; MTX 3; RST 8; GND¹; ANTENNA; GPIO1; GPIO2; GPIO3; GPIO4; GPIO5; GPIO6; GPIO7; 15 GND³ 13; GND⁴ 22; CTS 5; RTS 6; SXDIO2 7 SWDIO 9; VBAT 14; SWCLK 10; GND² 11; ANT301; VBAT; HOST_RST; GPIO1 GPIO2 GPIO3 GPIO4 GPIO5; GPIO6 HOST_CTS; HOST_RTS; HOST_TX; HOST_RX

Interface da Antena é um Throug Hole para
uso da antena helicoidal de 900MHz da
C3-PO Tecnologia.

Interface de comunicação
com o MCU Host

com Sensores

Interface de gravação
do STM32G0 do Módulo

Designed by: Airton Toyofuku
Revised by:
Customer:
Rev: 0.2

Modulo LoRaONE
LoRaONE board Lite
Sheet:

26/10/2020 16:29 D:\Workspace\Eagle\quadrar-loraone-board-lite\LoRaONE board Lite\LoRaONE board Lite.sch (LORA: Sheet: 1/1)

A

A

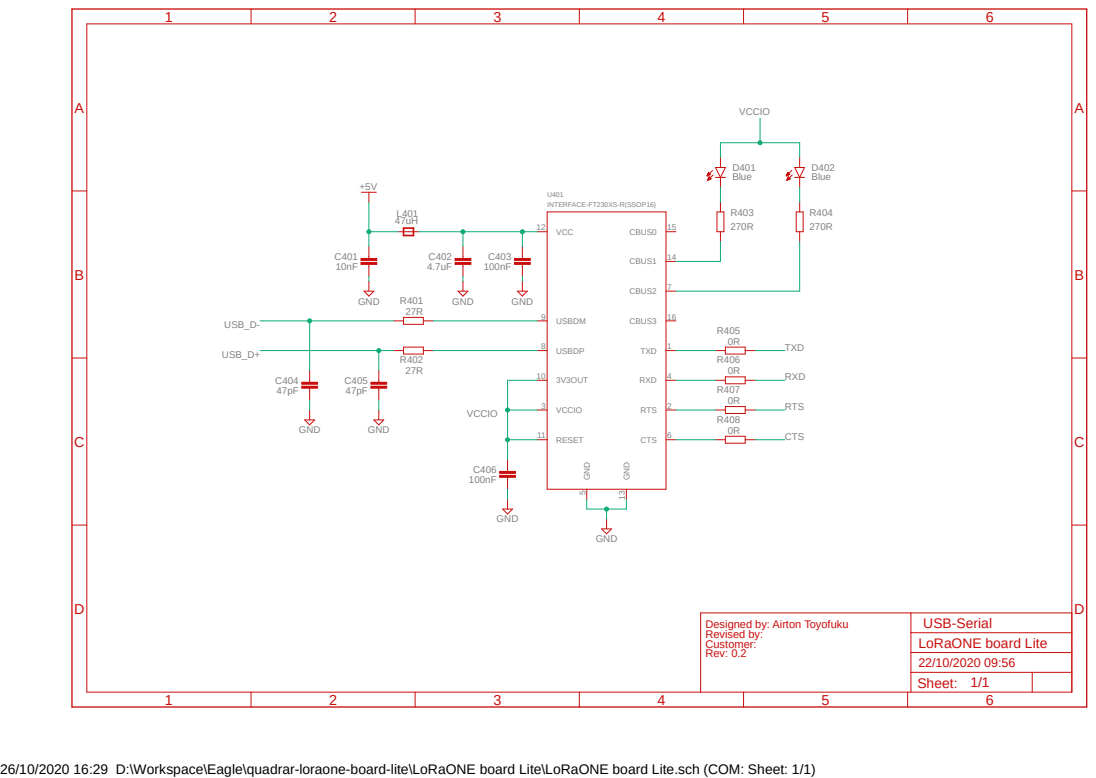
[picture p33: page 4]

Designed by: Airton Toyofuku
Revised by:
Customer:
Rev: 0.2

26/10/2020 16:29 D:\Workspace\Eagle\quadrar-loraone-board-lite\LoRaONE board Lite\LoRaONE board Lite.sch (COM: Sheet: 1/1)

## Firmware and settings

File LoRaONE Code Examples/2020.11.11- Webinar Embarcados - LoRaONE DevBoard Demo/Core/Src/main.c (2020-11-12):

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
/* Includes ------------------------------------------------------------------*/
#include "main.h"
#include "rtc.h"
#include "usart.h"
#include "gpio.h"

/* USER CODE BEGIN Includes */
#include "stdio.h"
#include "string.h"
#include "quadrar_gps.h"
#include "quadrar_loraone.h"
#include "dwt_stm32_delay.h"
#include "ds18b20.h"

/* USER CODE END Includes */


void SystemClock_Config(void);
/**
  * @brief  The application entry point.
  * @retval int
  */
int main(void)
{
  /* USER CODE BEGIN 1 */

	quadrar_gps_data_t GPSData;
	bool retc = 0;
	int32_t res = 0;
	float temp = 0;
	char buf[50];


  /* USER CODE END 1 */

  /* MCU Configuration--------------------------------------------------------*/

  /* Reset of all peripherals, Initializes the Flash interface and the Systick. */
  HAL_Init();

  /* Configure the system clock */
  SystemClock_Config();

  /* Initialize all configured peripherals */
  MX_GPIO_Init();
  MX_USART2_UART_Init();
  MX_RTC_Init();
  MX_UART4_Init();
  MX_USART1_UART_Init();
  /* USER CODE BEGIN 2 */

  quadrar_gps_init();

  DWT_Delay_Init();

  retc = Ds18b20_Init();
  if (!retc) {
	while(1);
  }

  for(;;)
  {
	  res = quadrar_loraone_init();
  if(!res)
	  break;
  }

  /* USER CODE END 2 */

  /* Infinite loop */
  /* USER CODE BEGIN WHILE */
  while (1)
  {
    /* USER CODE END WHILE */
	  quadrar_gps_get_data(&GPSData);
	  if(GPSData.fix == 'A')
	  {

		  memset(buf, 0x00, sizeof(buf));
		  sprintf(buf, "0%.6f", GPSData.latitude);
		  quadrar_loraone_send_data(1, buf);
		  HAL_Delay(10000);

		  memset(buf, 0x00, sizeof(buf));
		  sprintf(buf, "1%.6f", GPSData.longitude);
		  quadrar_loraone_send_data(1, buf);
		  HAL_Delay(10000);
	  }

	  Ds18b20_ManualConvert(&temp);
	  memset(buf, 0x00, sizeof(buf));
	  sprintf(buf, "2%.2f", temp);
	  quadrar_loraone_send_data(1, buf);

	  HAL_Delay(10000);
    /* USER CODE BEGIN 3 */
  }
  /* USER CODE END 3 */
}

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


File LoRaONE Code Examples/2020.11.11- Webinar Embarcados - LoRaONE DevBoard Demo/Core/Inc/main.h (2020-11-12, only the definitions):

#define B1_Pin GPIO_PIN_13
#define B1_GPIO_Port GPIOC
#define USART_TX_Pin GPIO_PIN_2
#define USART_TX_GPIO_Port GPIOA
#define USART_RX_Pin GPIO_PIN_3
#define USART_RX_GPIO_Port GPIOA
#define LD2_Pin GPIO_PIN_5
#define LD2_GPIO_Port GPIOA
#define LoRa_TX_Pin GPIO_PIN_9
#define LoRa_TX_GPIO_Port GPIOA
#define LoRa_RX_Pin GPIO_PIN_10
#define LoRa_RX_GPIO_Port GPIOA
#define TMS_Pin GPIO_PIN_13
#define TMS_GPIO_Port GPIOA
#define TCK_Pin GPIO_PIN_14
#define TCK_GPIO_Port GPIOA
#define GPS_TX_Pin GPIO_PIN_10
#define GPS_TX_GPIO_Port GPIOC
#define GPS_RX_Pin GPIO_PIN_11
#define GPS_RX_GPIO_Port GPIOC
#define SWO_Pin GPIO_PIN_3
#define SWO_GPIO_Port GPIOB

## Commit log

2020-10-15 - Initial Commit;
    [copper_bottom.gbr, copper_top.gbr, drill_1_16.xln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]
2020-10-22 - Alterado o silkscreen_bottom da DevBoard;
    [copper_bottom.gbr, copper_top.gbr, drill_1_16.xln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]
2020-11-12 - Atualizado o README; - Incluida apresentação do Webinar do dia 11/11/2020 no Embarcados; - Incluido esquema elétrico da DevBoard; - Incluidos codigos exemplos em C, utilizados no Webinar;
    [copper_bottom.gbr, copper_top.gbr, drill_1_16.xln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]
2020-11-12 - Incluido Script de parse dos dados na Tago, referente ao Webinar do dia 11/11/2020 no Embarcados

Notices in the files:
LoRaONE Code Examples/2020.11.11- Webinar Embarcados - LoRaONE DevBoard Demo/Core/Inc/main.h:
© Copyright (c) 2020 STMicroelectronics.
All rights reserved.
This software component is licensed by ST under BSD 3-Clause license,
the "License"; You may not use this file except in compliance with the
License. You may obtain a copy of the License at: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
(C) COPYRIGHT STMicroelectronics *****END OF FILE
